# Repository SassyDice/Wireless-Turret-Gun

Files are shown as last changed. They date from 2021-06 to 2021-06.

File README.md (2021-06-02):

# Wireless Turret Gun
 Turret prototype that can be controlled both via computer and android with BT module. If you want to use the ready '.exe' file of LFK, you can download it from LFK's page. All the necessary explanations are available in the files.
# *
# *
# Kablosuz Taret Silahı
 BT modulü ile hem bilgisayar hemde android üzerinden kontrol edilebilen taret prototipi. LFK'nin hazır '.exe' dosyasını kullanmak istiyorsanız LFK'nın sayfasından indirebilirsiniz. Gerekli tüm açıklamalar dosyalarda mevcuttur.

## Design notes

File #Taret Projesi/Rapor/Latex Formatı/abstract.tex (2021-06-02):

The goal of the project; to create a turret that can be remotely controlled in line with the objectives such as ensuring life safety in military areas, gaining superiority against terrorist threats, benefiting domestic production and keeping up with the developing technology. Necessary circuits will be installed on the turret, the 3D mold of which is printed, and the movement will be carried out to lock the turret to the target through the user via computer or mobile, and this information will be sent to the turret via the wireless communication module HC-05 and its shot will be provided. In the project, servo motors are moved by the user's computer mouse or telephone touch screen and this movement is controlled by Arduino NANO microcontroller. Here the Arduino platform is used to control everything.
\vspace{3mm}

 \begin{tabular}{ll}
 	{\textbf{Keywords}:} & {Turret, Arduino, Remotely Control, Bluetooth, Military Projects.}  \\   	
 \end{tabular}

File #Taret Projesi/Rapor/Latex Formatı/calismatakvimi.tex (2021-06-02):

Çalışma Takvimi
\label{CH:Bolumcalismatakvimi}

\begin{figure}[H]
	\centering
	
   	\label{fig:CalismaTakvimiDM}
\end{figure}

\clearpage

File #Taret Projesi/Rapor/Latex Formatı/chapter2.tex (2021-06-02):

\chapter{B: ARDUİNO}
\label{IkinciBolum}

	Arduino kullanımı ilk başta pek az kişi tarafından bilinmekteydi. kökenleri ise Wiring ve Processing projelerine dayanmaktadır. Henüz programlama deneyimi olmayan kişilere programlamayı öğretebilmek amacıyla processing programlama dili ve geliştirme ortamı oluşturulmuştur. 
    Teknik bilgisi az olan insanlara bilgi besleme adına da kolaylık sağlayan arduino, çevresiyle etkileşim içinde olan interaktif nesneler oluşturmak isteyen tasarımcılar için de büyük kolaylık sağlamaktadır.
    Arduino bir Giriş/Çıkış kartı ve Processing dilinin uygulamasını da dahilinde bulunduran bir fiziksel programlama platformudur. Arduino bilgisayar üzerinde çalışan yazılımlarda kullanıldığı gibi tek başına çalışan interaktif nesneler oluşturmak için de kullanılabilir.
    
	Arduino’ nun neden bu kadar çok tercih edildiğini maddeler halinde gösterirsek:  
    
\begin{itemize}
\item Windows, Linux, Mac gibi bütün platformlarda çalışabilen geliştirme ortamı ve sürücülerinin kurulumu çok kolay olmaktadır.  
\end{itemize}

\begin{itemize}
\item Zengin bir kütüphane barındırdığından Birçok karmaşık işleme kolaylık sağlayabilmektedir.
\end{itemize}
	
\begin{itemize}
\item İçerisinde aktarılan kodlar/programlar oldukça hızlı çalışmaktadır. 
\end{itemize}

\begin{itemize}
\item Başka donanımlarla da çalışabilmesi adına ek donanımlar içermektedir. Bu karta bağlanamayan sensör çeşidi yok desek yeridir.
\end{itemize}
    
\begin{itemize}
\item Benzer diğer devre kartlarına kıyasla fiyatı oldukça uygundur.
\end{itemize}
   
\begin{itemize}
\item Açık kaynak kodlu olması kullanmak isteyen herkesin özgürlüğine olanak sağlamaktadır. Misal bir eğitim kurumu Arduino için lisans parası ödemeden rahatça kullanabilir. KAYNAK [5],[6]
\end{itemize}

\clearpage

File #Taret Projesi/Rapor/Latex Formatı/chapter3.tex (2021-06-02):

B.2: Arduino Uno 
\label{UcuncuBolum}

	Geliştirilen birçok projede kullanılan en popüler devre kartıdır. Üzerinde birkaç donanım barındırmaktadır. Bunlar: Atmega328 mikrodenetleyici, 16 MHz kristal, güç regülatörü, USB bağlantı portu, gibi bileşenler bulunuyor. Üzerindeki USB dönüştürücü sayesinde hem gerekli kodlar aktarılabilmekte hem de bilgisayar ile iletişim kurulabilmektedir. Kart, üzerindeki fiş jakı sayesinde adaptör tarafından veya üzerindeki USB portu sayesinde kurulan USB bağlantısı tarafından beslenebilmektedir. Arduino Uno kartının ön ve arka görünümü sırasıyla, Şekil 2 ve Şekil 3'de gösterilmiştir.

\begin{figure}[H]
	\centering
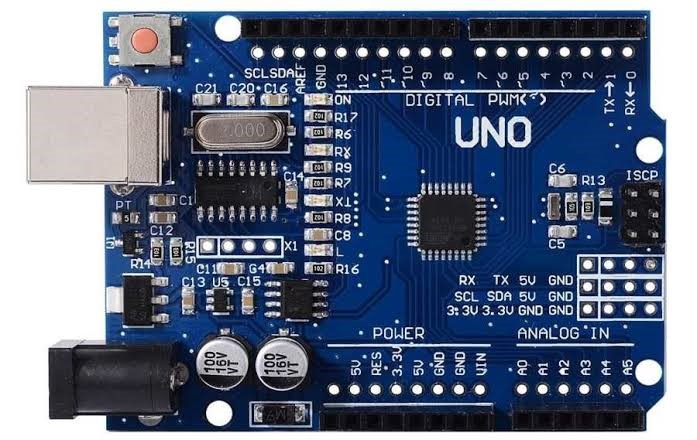
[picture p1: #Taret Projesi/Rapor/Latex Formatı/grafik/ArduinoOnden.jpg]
	
    \caption{Arduino Uno (Klon) kartının ön görünümü}
	\label{fig:ArduinoOndenDM}
\end{figure}
\begin{figure}[H]
	\centering
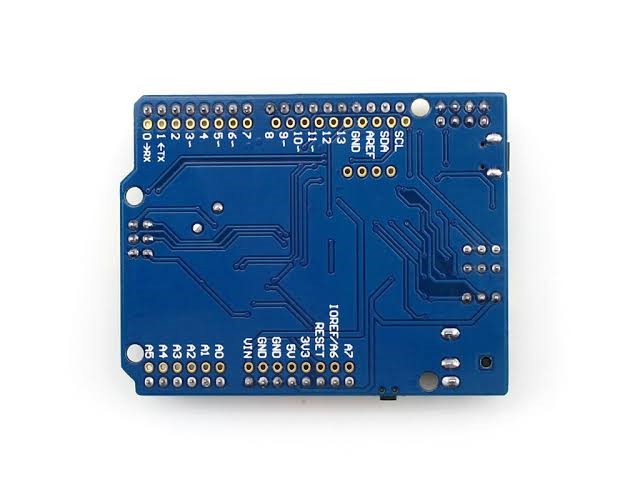
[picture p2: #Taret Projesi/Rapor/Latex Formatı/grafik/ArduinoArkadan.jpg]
	
    \caption{Arduino Uno (Klon) kartının arka görünümü}
	\label{fig:ArduinoArkadanDM}
\end{figure}

\clearpage

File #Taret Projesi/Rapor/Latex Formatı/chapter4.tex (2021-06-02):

B.3: Servo Motor
\label{DorduncuBolum}

	Servo motorlar çoğu projenin hareketini sağlamakta ve olmazsa olmazlardandır. CNC'lerde, model uçaklarda, RC arabalarda, 3D Printerlarda ve küçük güçteki birçok robot uygulamalarında kullanılmaktadır. Servo motor içerisinde geri besleme potansiyometresi, DC elektrik motoru, DC motor konum kumanda elektroniği ve planetar dişli sistemi bulunmaktadır. Bu motorlar projemde tasarlanan taretin gövde, baş ve tetikleme hareketlerini gerçekleştirmek amacıyla kullanılacaktır. Servo motorun blok diyagramı, projede kullanılan modeli ve devre şeması sırasıyla, Şekil 4, Şekil 5 ve Şekil 6’da gösterilmiştir.

\begin{figure}[H]
	\centering
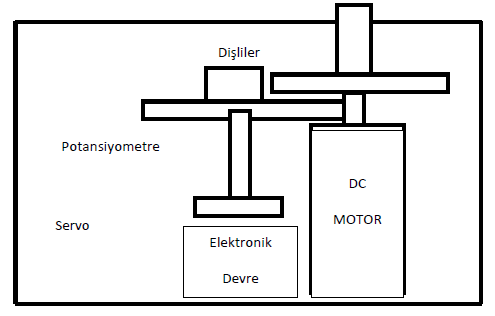
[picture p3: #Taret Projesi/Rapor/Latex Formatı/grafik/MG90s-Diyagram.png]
	
    \caption{Servo motorların genel iç blok diyagramı}
	\label{fig:MG90s-DiyagramDM}
\end{figure}
\begin{figure}[H]
	\centering
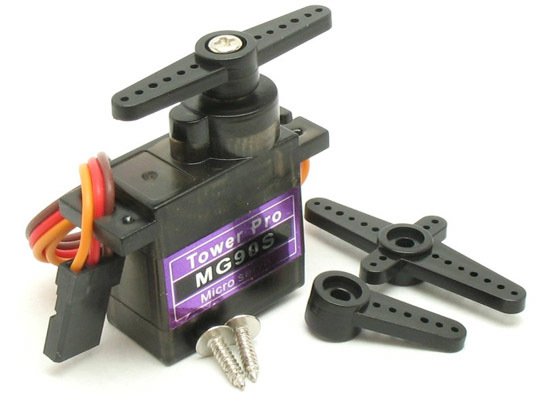
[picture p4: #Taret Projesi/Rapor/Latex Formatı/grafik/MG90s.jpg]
	
    \caption{Projede Kullanılan MG90s Servo}
	\label{fig:MG90sDM}
\end{figure}
\begin{figure}[H]
	\centering
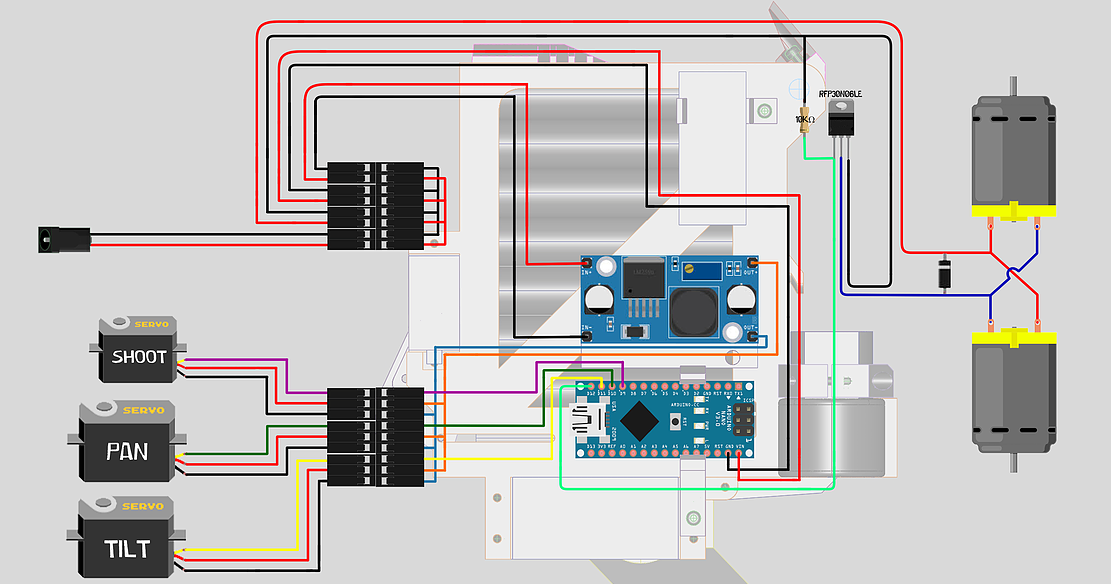
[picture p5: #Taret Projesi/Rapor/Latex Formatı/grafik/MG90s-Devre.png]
	
    \caption{Servo Motorların Projedeki Devre Şeması}
	\label{fig:MG90s-DevreDM}
\end{figure}

\clearpage

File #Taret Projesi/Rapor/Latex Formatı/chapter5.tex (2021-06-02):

\textbf{B.4: HC-05 Bluetooth Modül}
\label{YedinciBolum}

	HC-05 Bluetooth modülü,  kablosuz seri haberleşme projeleri için yapılmıştır. Bu modül bluetooth 2.0’ı destekleyen, 2.4GHz frekansında haberleşme yapılmasını sağlar. Haberleşme esnasında açık alanda yaklaşık 10 metre haberleşme mesafesine sahiptir. Modülün haberleşme bağlantısı serial yani UART olduğundan kolay ve hızlı bir kullanımı vardır. Üzerinde bulunan RX ve TX pinleri sayesinde iletişim sağlanır. Bu pinler kullanılacak olan devre kartınının sırasıyla TX ve RX pinlerine bağlanır. Ayrıca bu pinler yardımıyla AT komutlarını kullanarak modülün isim, şifre,baud rate değeri, gibi çeşitli özellikleri değiştirebilir. KAYNAK [3]
    
	Projede ise bu modül kablosuz haberleşme için kullanılmaktadır. Bilgisayar veya mobil üzerinden alınan analog veriler bu modül sayesinde tarete aktarılmaktadır. Bu sayede kullanıcı tarafından yapılan hareketleri anlık olarak taret üzerinde de gözlemleyebiliriz. Bluetooth modül Şekil 7de gösterilmiştir.

\begin{figure}[H]
	\centering
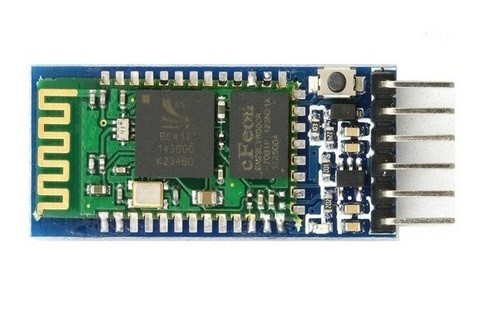
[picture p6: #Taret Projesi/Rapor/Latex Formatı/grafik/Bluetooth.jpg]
	
    \caption{Projede Kullanılan HC-05 Bluetooth Modülü}
	\label{fig:BluetoothDM}
\end{figure}

\textbf{Dikkat:} HC-05 Bluetooth modülü devre kartındaki 3.3V pinine bağlantı yapılarak veya uçları arasında dirençler bağlayarak çalıştırılması gerekmektedir. HC-06 Bluetooth modülü ise 5V pinine bağlantı yapılarak veya yine direnç bağlanarak çalıştırılmalıdır.

\textbf{Bilgi:} Kodları hatasız bir şekilde Arduino’ya aktarabilmek için Arduino üzerindeki RX ve TX pinlerine bağlı kabloları aktarma işleminden önce sökmek gerekiyor. Bu işlem yapılmazsa kod aktarımı sırasında portların meşgul olduğuna dair hata alabiliriz. 

\clearpage

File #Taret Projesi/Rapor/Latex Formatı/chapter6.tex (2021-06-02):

\textbf{B.5: 3D Taret Modeli}
\label{SekizinciBolum}

Taretin baskısı 3D yazıcılar vasıtasıyla PLA+  Filament kullanılarak yapıldı. Kendi oluşturmuş olduğum 3D modelleri ile Github üzerindeki üyerlerin modellerini mix ederek aşağıdaki modelleri elde etmiş oldum. 3D modeli oluşturmak için Blender programını kullandım. Taretin 3D modelleri Şekil 9’da gösterilmiştir. KAYNAK [1]

\begin{figure}[H]
	\centering
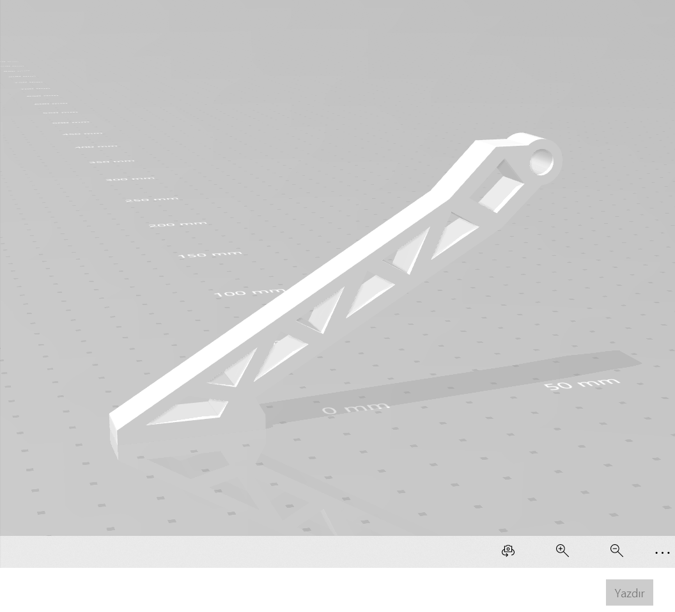
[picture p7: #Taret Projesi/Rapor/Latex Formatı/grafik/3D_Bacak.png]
	
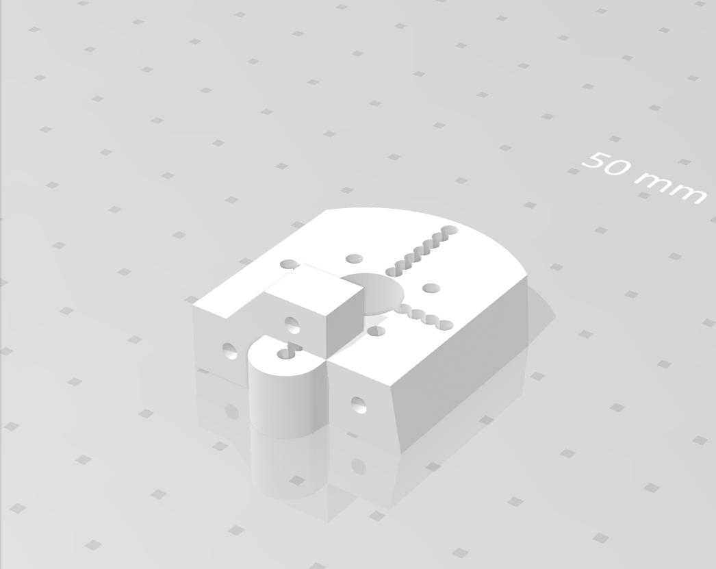
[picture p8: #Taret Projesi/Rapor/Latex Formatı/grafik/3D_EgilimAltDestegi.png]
    
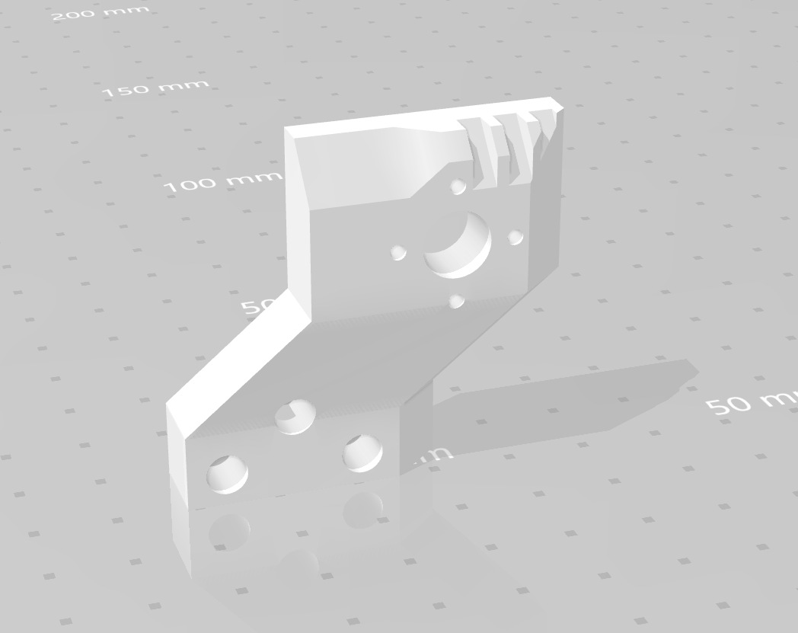
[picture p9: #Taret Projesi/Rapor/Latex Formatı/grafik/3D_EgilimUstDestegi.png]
    
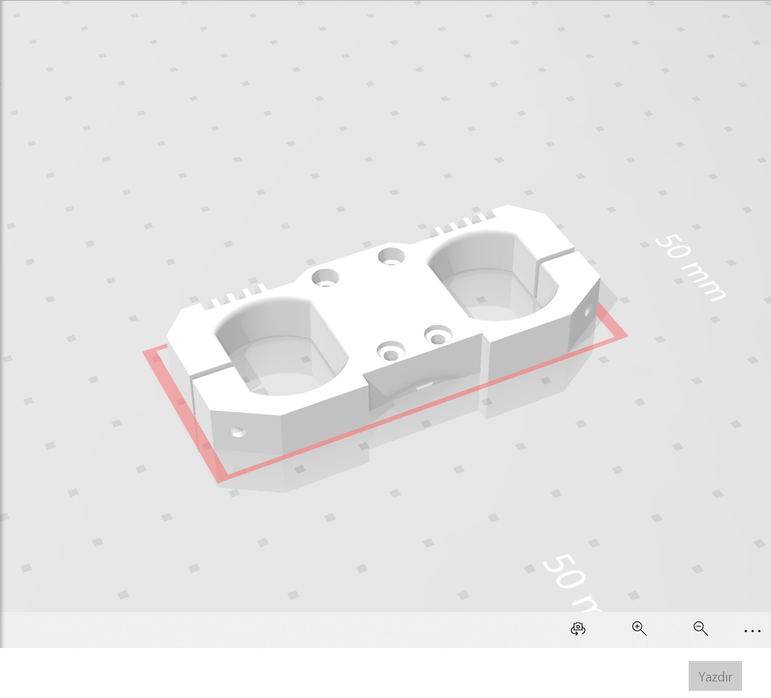
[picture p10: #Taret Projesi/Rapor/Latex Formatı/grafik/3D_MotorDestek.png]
    
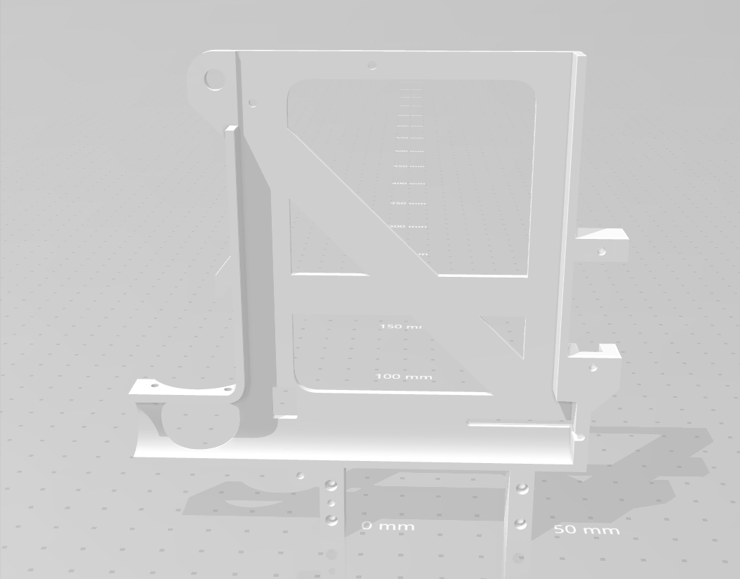
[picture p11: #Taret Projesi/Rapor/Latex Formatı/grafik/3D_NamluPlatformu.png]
    
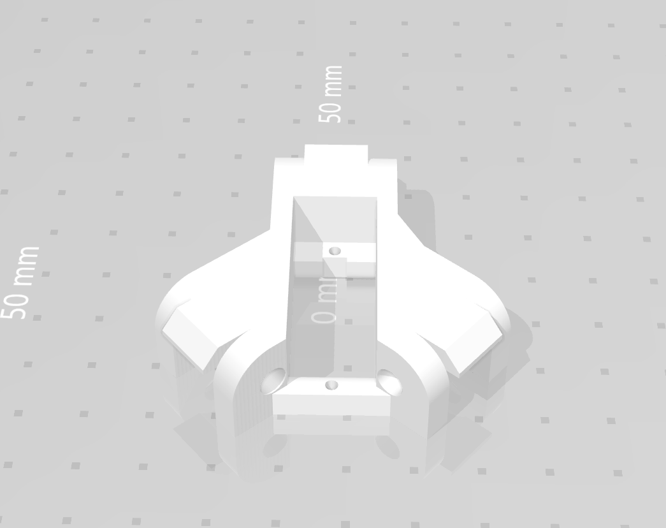
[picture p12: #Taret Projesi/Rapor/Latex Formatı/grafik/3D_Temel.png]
    
    
    \caption{Taret 3D Model Örnekleri}
    \label{fig:Taret1,2,3,4,5,6DM}
\end{figure}

\clearpage

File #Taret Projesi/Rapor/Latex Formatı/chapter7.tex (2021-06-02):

\textbf{C: Programlama Aşaması }
\label{DokuzuncuBolum}

Tüm devrelerin montajı tamamlandı ve projenin programlama aşamasına geçildi. Bu aşamada ilk önce fare hareketlerinin analog değerleri serial monitörden okunarak hassasiyet değerlendirmesi maksatıyla tam değerleri bulundu. Arduino NANO devre kartı ise okunan değerleri projede kullanılan servo motorlara dikey ve yatay açısal bilgileri gönderecek şekilde programlandı. Tüm kodlamalar Arduino IDE programı vasıtasıyla Bilgisayardan USB kablo ile Arduino NANO Mikrodenetleyicisine aktarıldı.

\begin{figure}[H]
	\centering
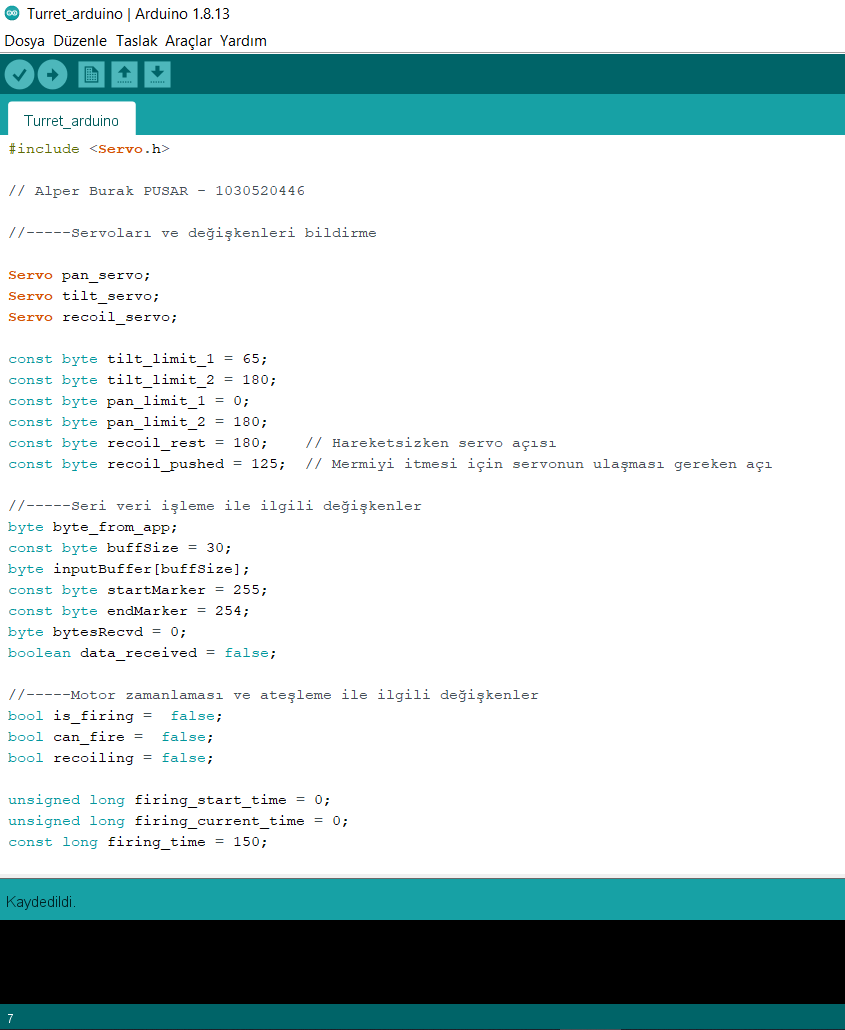
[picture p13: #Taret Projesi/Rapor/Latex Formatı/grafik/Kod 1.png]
	
	\label{fig:KodDM}
\end{figure}
\begin{figure}[H]
	\centering
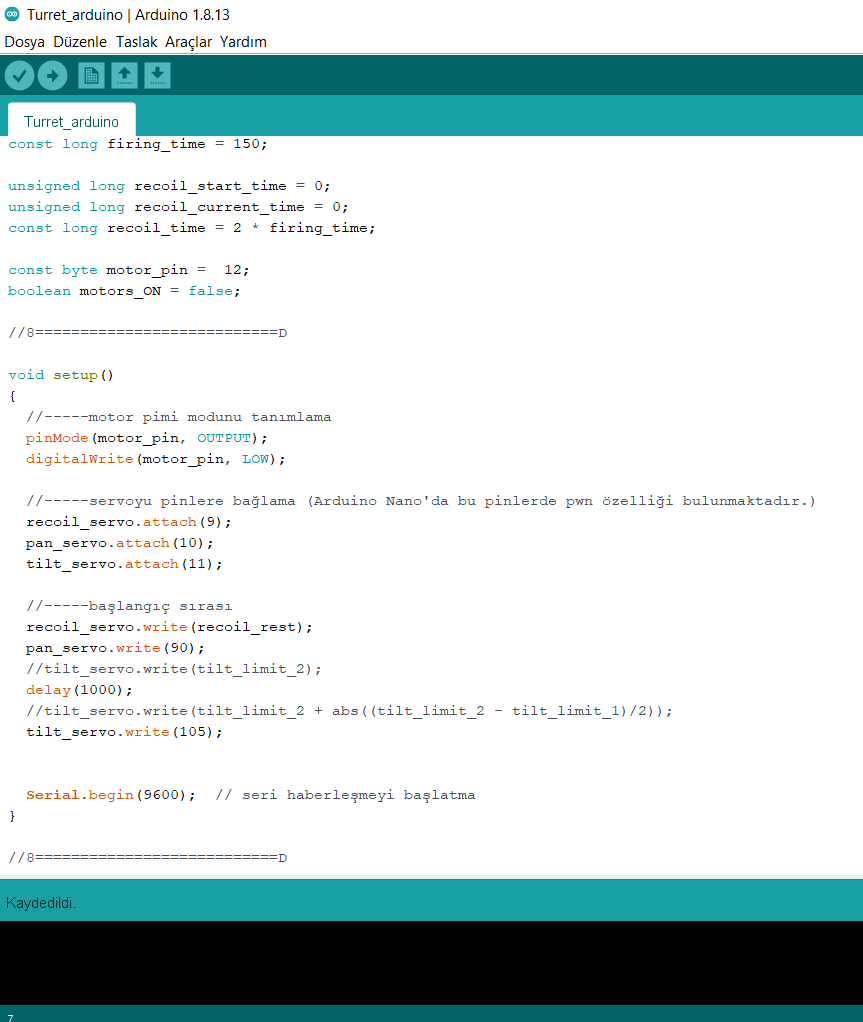
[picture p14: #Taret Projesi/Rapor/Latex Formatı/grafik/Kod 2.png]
	
	\label{fig:KodDM}
\end{figure}
\begin{figure}[H]
	\centering
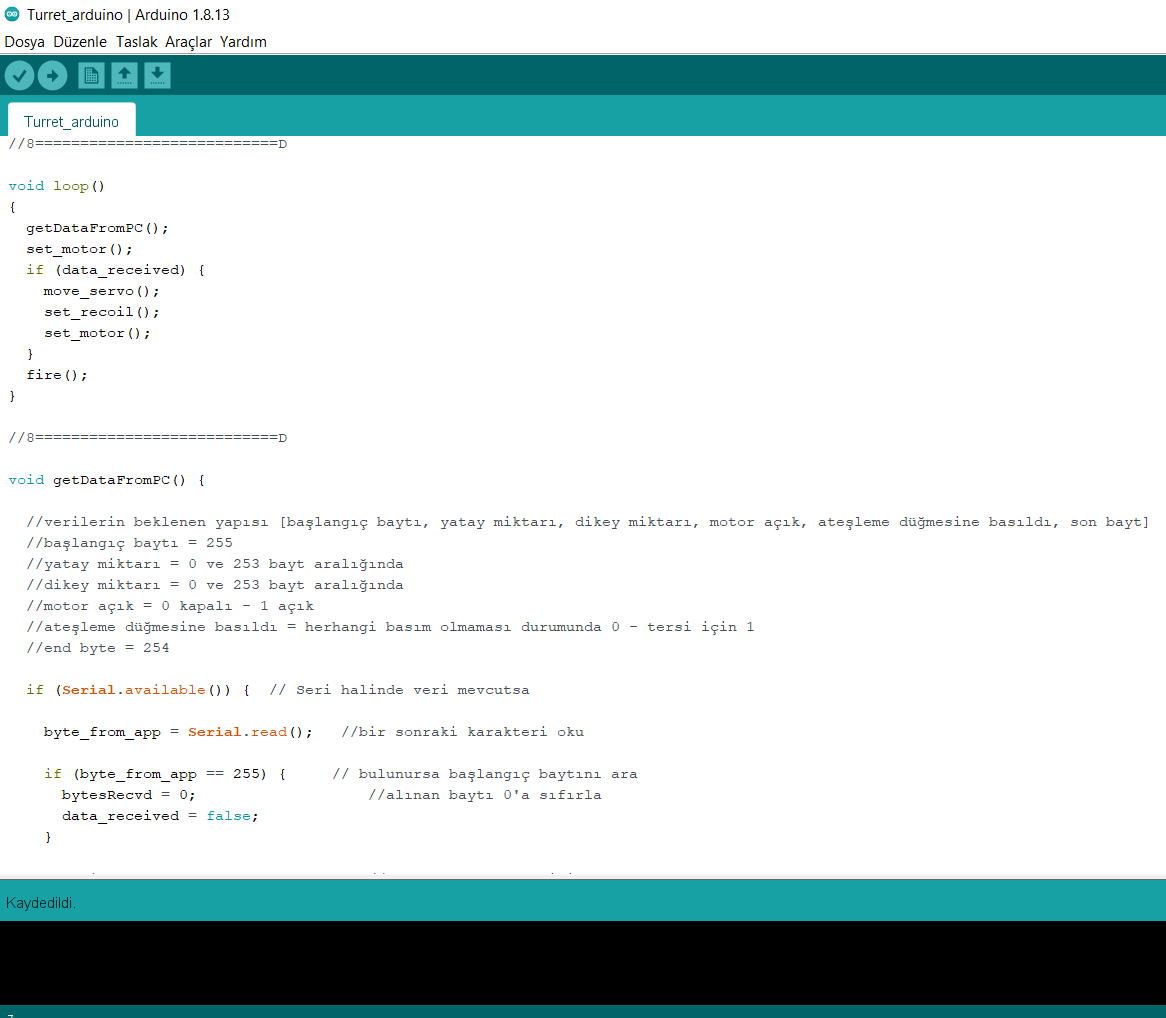
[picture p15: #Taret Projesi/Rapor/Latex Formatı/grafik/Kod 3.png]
	
	\label{fig:KodDM}
\end{figure}
\begin{figure}[H]
	\centering
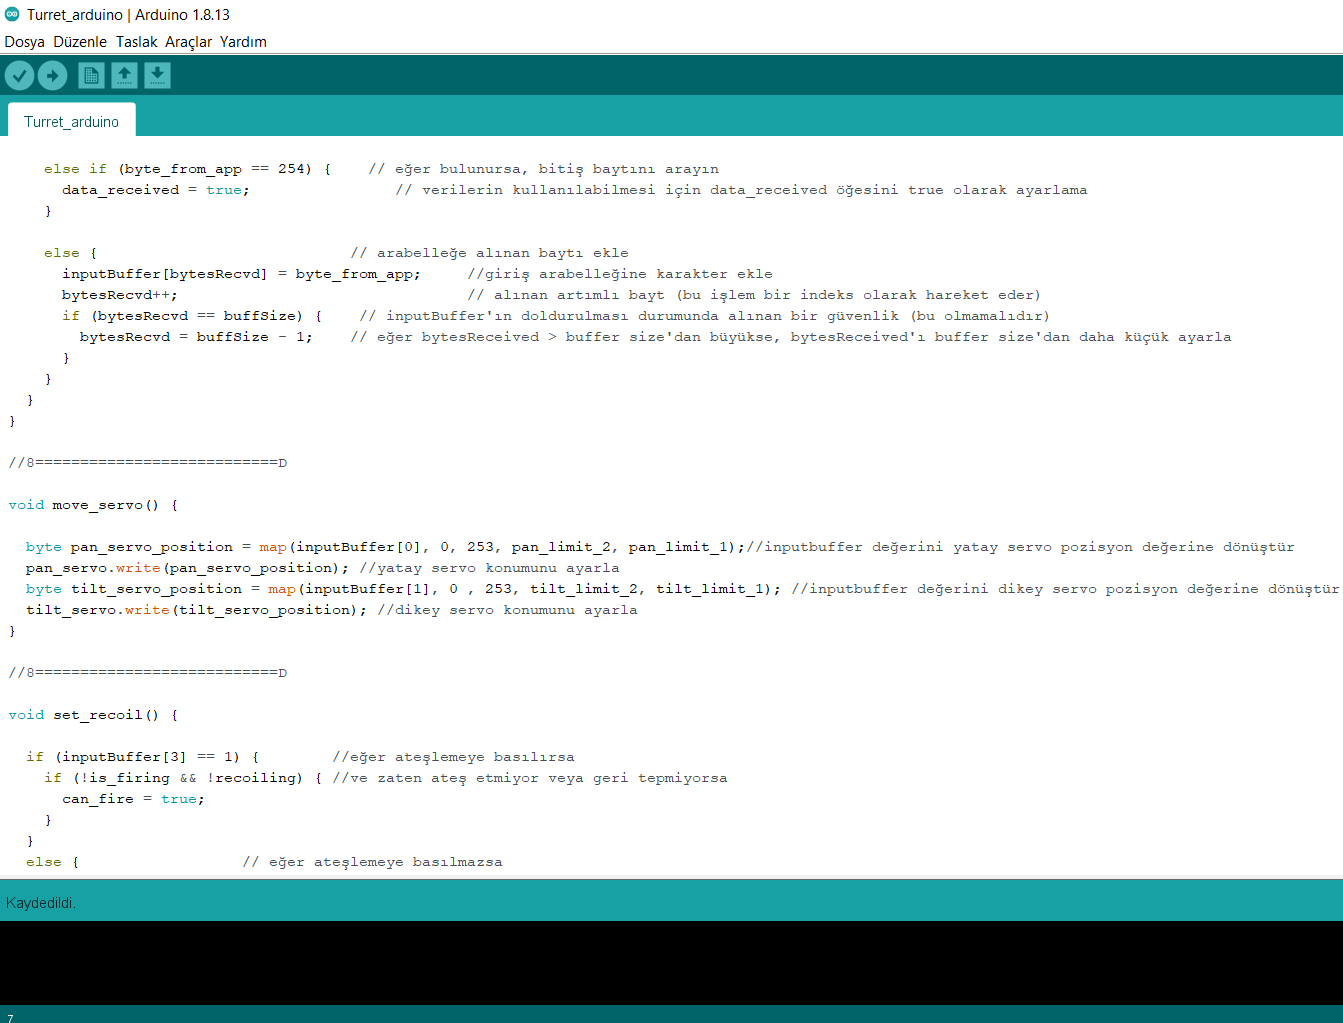
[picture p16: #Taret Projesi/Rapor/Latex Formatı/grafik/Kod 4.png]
	
	\label{fig:KodDM}
\end{figure}
\begin{figure}[H]
	\centering
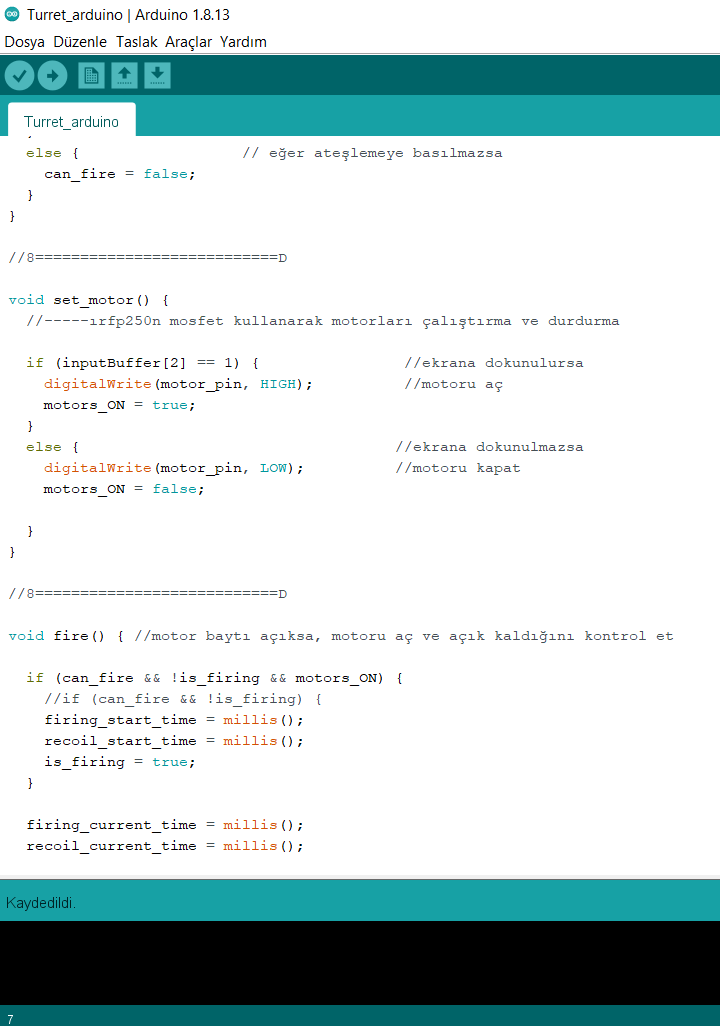
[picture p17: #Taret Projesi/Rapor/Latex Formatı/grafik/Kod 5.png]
	
	\label{fig:KodDM}
\end{figure}
\begin{figure}[H]
	\centering
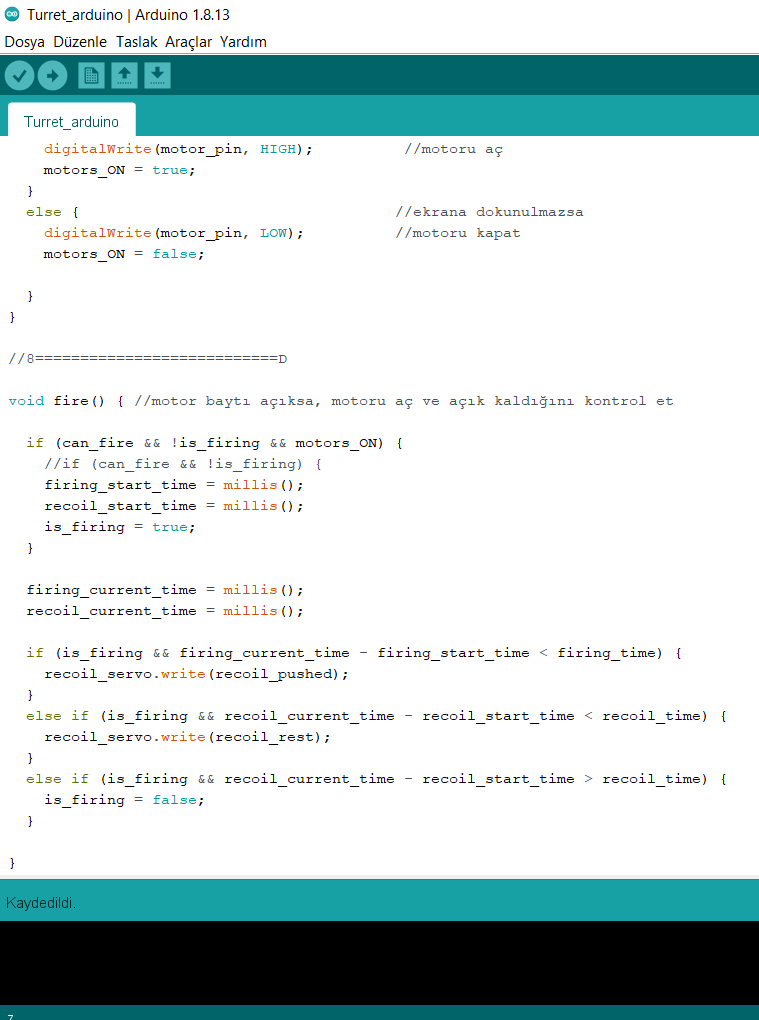
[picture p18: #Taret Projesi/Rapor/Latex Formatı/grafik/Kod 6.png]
	
	\label{fig:KodDM}
\end{figure}

\clearpage

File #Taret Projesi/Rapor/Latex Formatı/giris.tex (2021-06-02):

\label{CH:BolumGiris}

Günümüz teknolojisinde endüstriyel, tıp ve askeri alanlar başta olmak üzere birçok alanda robotik sistemlere olan ilgi artmaktadır. Hobi olarak veya üniversite proje yarışmaları ile yapılan robotik sistemlerin yanı sıra askeri güç amaçlı, uluslararası rekabet ve ülke sınırları dahilindeki terör sorununu bitirmek amaçlı yapılan ve özellikle de AR-GE çalışmaları sonucu ortaya çıkarılan birçok savunma sanayi ürünü sunulmuştur. Tasarladığım uzaktan kontrollü taret projesinin, bir insanın yapamayacağı derecede hassasiyet elde ederek hedefe net kitlenebilme ve daha da önemlisi can kaybının azalacağına yönelik büyük hizmet sunacağı düşünülmektedir. Bu proje 3D yazıcı yardımıyla tasarlanmış taretin, kullanıcının vereceği komutları doğru uygulayabilmesi esasına dayanmaktadır. Tasarlanan taretin devrelerine bağlı durumda bulunan HC-05 Bluetooth modeli, işlevini uzaktaki bir kullanıcının vereceği komutları veri kaybı olmadan tarete ulaştırabilmesi amacıyla devreye eklenmiştir. Kullanıcı ile taret arasındaki haberleşme kablosuz olarak sağlanmıştır. Proje, bilgisayar veya mobil ile uyumlu nitelikte olacaktır.  Eğer ki bilgisayar üzerinden haberleşme sağlanıyorsa, fare üzerindeki hareketilerin veri kodları arduino uyumu için  kendi kütüphanesine bağlı kodlar vasıtasyıla compile edilir ve servo motorlara iletilir. Hem gövde hem de baş kısmında bulunan servolar sayesinde yatay ve dikey hareket kabiliyeti tarete akatarılmış olur. Plastik mermilerin atışının gerçekleşmesi ise namlu ucuna yerleştirilen 2 adet DC motorun sürekli dönüşü sayesinde ikisinin arasına temas eden mermiyi hızlı bir ivmeyle fırlatması şeklinde gerçekleşir. Tüm bu işlemlerin programlanması Arduino NANO mikrodenetleyicisi üzerinden kurulan devre sayesinde kontrol edilmiştir.

\clearpage

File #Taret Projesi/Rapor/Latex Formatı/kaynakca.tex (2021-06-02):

\textbf{KAYNAKLAR}
\label{CH:BolumKaynakca}

[1]. Github Users, Multi persons, Arduino Turret, Available: https://github.com/

[2]. The Extendedsystem website. Available: http://www.extendedsystems.com/

[3]. Haartsen, J. C., The Bluetooth Radio System, IEEE Personal Communications 

[4]. Çamoğlu, D., Kontrollü Robotik, Dikeyeksen Yayıncılık, Şubat 2011. 

[5]. Taşdemir, C., Arduino, Dikeyeksen Yayın Dağıtım, Yazılım ve Eğitim Hizmetleri San. ve Tic. Ltd. Şti., İstanbul, 2012. 

[6]. D. İbrahim, PIC Mikrokontrolör Robot Projeleri, Bileşim Yayıncılık Fuarcılık ve Tanıtım Hizmetleri A.Ş., İstanbul, Türkiye, 2005.

\clearpage

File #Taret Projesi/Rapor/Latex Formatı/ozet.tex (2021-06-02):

\label{CH:BolumOzet}

Projenin amacı; askeri alanlarda can güvenliğini sağlamak, terör tehtitlerine karşın üstünlük sağlamak, yerli malı üretimine fayda sağlamak ve gelişen teknolojiye ayak uydurmak gibi hedefler doğrultusunda uzaktan kontrol edilebilen bir taret ortaya çıkarmaktır. 3D kalıbı basılan taretin üzerine gerekli devreler kurulup, bilgisayar veya mobil üzerinden kullanıcı aracılığıyla taretin hedefe kitlenmesi için hareketi gerçekleştirilecek. Bu bilgiler HC-05 bluetooth modülü aracılığıyla tarete anlık veri akışları gönderip atışı sağlanacaktır. Projede, kullanıcının bilgisayar faresi veya telefon dokunmatik ekranı vasıtasıyla servo motorlar hareket ettirilmektedir. Yapılan tüm bu işlemler Arduino NANO ile kontrol edilmektedir.
               
\clearpage

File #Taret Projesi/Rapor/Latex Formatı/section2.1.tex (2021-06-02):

\clearpage
\section{B.1: Arduino Çeşitleri: }
\label{CH:AltBolum2.1}

1. Arduino Uno 	

2. Arduino Nano	

3. Arduino Mega  

4. Arduino Mini ve Mini Pro 

5. Arduino Bluetooth 

6. Arduino Lilypad 20 	

7. Arduino Leonardo

8. Arduino Adk 		

9. Arduino Ethernet

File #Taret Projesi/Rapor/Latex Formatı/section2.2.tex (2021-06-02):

\clearpage
\section{B.1.1: KULLANILAN MALZEMELER}
\label{CH:AltBolum2.2}

Arduino Nano 		x 1 --------------------------------------- 9v Pil				x 1

M2x10 Vida			 30 civarı	---------------------------------- M5x20 Vida x3

MG90s - Servo Motor	  x 3 ----------------------------- Makaron Kablo

HC-05 Bluetooth Modül 	x 1 -------------------------- LM2596 Voltaj Regülatörü x1

3D Printer Taret Kalıbı -------------------------------- Dirençler (10k, 330, 680) x3

FR207 Doğrultucu Diyot			x 1 -------------------------- Super Glue + Spray

Jumper Kablo --------------------------------------------- 2.1x5.5mm Jak Fişi x1

RFP30N06LE mosfet   x1 -------------------------------- Type 130 DC Motor x2

1.5mm Metal Çubuk x1 --------------------------------- Dupont Konnektörler

\begin{figure}[H]
	\centering
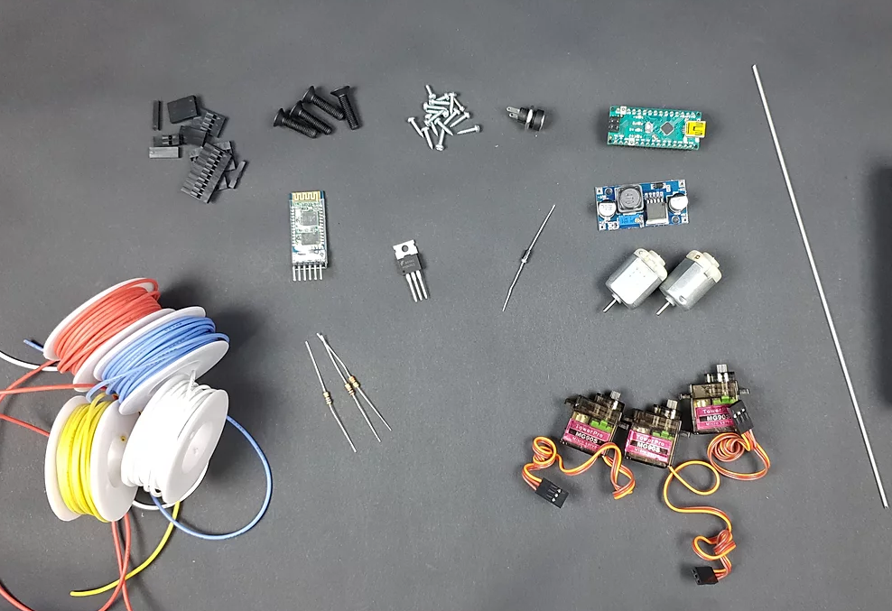
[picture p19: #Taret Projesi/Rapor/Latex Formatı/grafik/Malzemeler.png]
	
    \caption{Not: Projede Kullacağım Malzemeler (Bazı parçaları eksik ve 3D kalıp hariç görüntüsüdür.)}
	\label{fig:MalzemelerDM}
\end{figure}

\clearpage

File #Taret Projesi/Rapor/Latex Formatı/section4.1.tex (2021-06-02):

\textbf{B.3.1: TEKNİK ÖZELLİKLER:}
\label{CH:AltBolum4.1}

MG90s Servo Motor Özellikleri:

•	Çalışma tork: 2 kg/cm

•	Hızı: 0.11 sn/60° (4.8 V)

•	Çalışma aralğığı: 4.8 - 6.0 V

•	Çalışma sıcaklığı: 0°-55°

•	Ölü bant ayarı: 5 mikrosaniye

•	Dönme açısı: 180 derece

•	Çalışma gerilimi: 4.8 V - 6.0 VDC

•	Yapısal Malzeme: bakır metal diş, çekirdeksiz motor, çift bilyalı rulman

•	Boyutu: 23 x 12x 29 mm

\clearpage

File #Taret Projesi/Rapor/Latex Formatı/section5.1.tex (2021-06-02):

\textbf{B.4.1: TEKNİK ÖZELLİKLER:}
\label{CH:AltBolum7.1}

•	Çalışma Gerilimi: 3.3 V - 5 V,

•	Akım: 50 mA,

•	Bluetooth Protokolü: Bluetooth 2.0+EDR,

•	Haberleşme frekansı 2.4GHz,

•	Hassasiyet: ≤-80 dBm,

•	Çıkış Gücü: ≤+4 dBm,

•	Asenkron Hız: 2.1 MBps/160 KBps,

•	Senkron Hız: 1 MBps/1 MBps,

•	Güvenlik: Kimlik Doğrulama ve Şifreleme,

•	Boyutları: 43 x 16 x 7mm,

HC-05 Modülünün devre şeması Şekil 8’de gösterilmiştir.

\begin{figure}[H]
	\centering
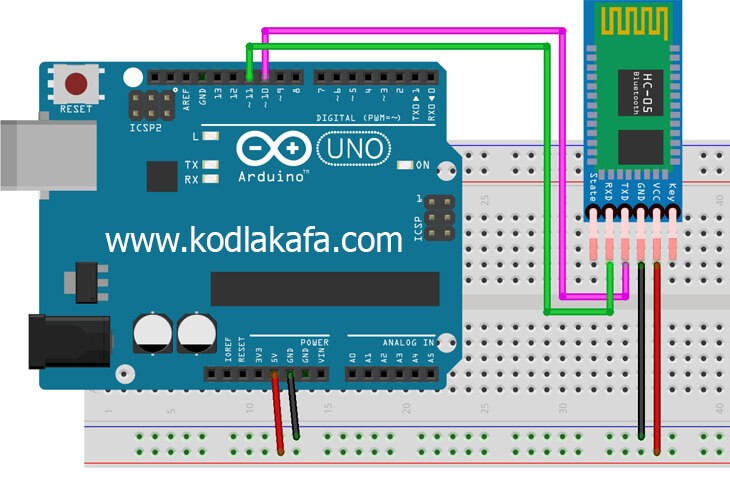
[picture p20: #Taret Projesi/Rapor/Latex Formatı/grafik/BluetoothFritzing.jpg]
	
    \caption{HC-05 Modülünün Bağlanma Şekli (Fritzing)}
	\label{fig:BluetoothFritzingDM}
\end{figure}

\clearpage

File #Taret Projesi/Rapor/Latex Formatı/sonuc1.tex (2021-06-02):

\textbf{D: SONUÇLAR }
\label{BolumSonuc}

	Yazılım ve Elektronik alanlarında yapılan yeni projeler ve devam eden çalışmaların en önemlileri insan sağlığını koruyacak türde veya global teknolojiye ayak uydurarak askeri ya da endüstriyel alanlarda gelişime açık olanlarıdır. Bu fikirle başladığım projeyi tamamlamak için amaçladığım gibi tareti kontol eden kişinin verdiği komutları veri kaybı olmadan tarete ulaşmasını sağlayabilmek vasıtasıyla tasarlanan taretin hedefe isabetli atışlarını gerçekleştirdim. Bu işlemin kullanıcı ve taret arasında kablosuz haberleşme ile sağlandığını vurgulamak gerekir.
    
Bu projeyi gerçekleştime aşamalarında birçok sıkıntıyla karşılaştım. İlk karşılaştığım sıkıntı satın almış olduğum arduino nano kartında arıza olmasıydı. Bu kartın hatalı olduğunu anlatıktan sonra yenisi temin ettim. ancak bu bozuk kartla işlem yapmaya kalkarken sanırsam hc-05 bluetooth modülümün de hasar aldığını farkettim ve onu da değiştirmek zorunda kaldım. Projede kullanılmasını uygun gördüğim FR207 hızlı diyot ve rfp30n06le mosfeti birçok yerde aradım ancak bulamadım. diyotun özellikleri 2A 100V değerlerini gösterirken mosfet ise 30A 60V değerlerini göstermekte. Ancak değindiğim gibi bu modülleri temin edemedeğimden bunların yerine BY298 hızlı diyot (2A 400V) ve ırfp250n mosfet (30A, 200V) modüllerini kullanmaya karar verdim. Bu modüller DC motorlara bağlantı kurduğundan, muhtemelen bu karar değişimden dolayı proje testi esnasında asıl büyük sıkıntıyı burada yaşadım. DC motorların güç kaçağı veya geri besleme gibi sıkıntılardan olsa gerek devreyi stabil tutamadım. bu kısım beni gerçekten çok uğraştırdı. İlk başlarda sıkıntının ne olduğunu da tam anlayamadım. En sonunda Voltaj dengesini sağlayarak devreyi stabil tutabildim.

Projenin sunumunu ayrı şekilde temin edeceğimden bu final tezine ekleme yapabileceğim kodlama, sonuç ve yorumlamalardan başka birşey kalmıyor. Zaten projenin son halini yazımdan çok videodaki anlatıma döktüm. Eminim yeterli gelecektir.

\clearpage

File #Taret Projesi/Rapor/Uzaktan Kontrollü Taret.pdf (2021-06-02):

T.C.

## ERCİYES ÜNİVERSİTESİ MÜHENDİSLİK FAKÜLTESİ

## UZAKTAN KONTROLLÜ TARET

## Hazırlayan

## Alper Burak PUSAR

1030520446

## Danışman Doç. Dr. Celal ÖZTÜRK

## Bilgisayar Mühendisliği

## Bitirme Ödevi

## Temmuz 2020 KAYSERİ

i

“Uzaktan Kontrollü Taret” adlı bu çalışma, jürimiz tarafından Erciyes

Üniversitesi Bilgisayar Mühendisliği Bölümünde Bitirme Ödevi olarak kabul

edilmiştir.

13/07/2020

JÜRİ :

Danışman : Doç. Dr. Celal ÖZTÜRK

Üye | :
Üye | :

ONAY :

Yukarıdaki imzaların, adı geçen öğretim elemanlarına ait olduğunu onaylarım.

.... / .... /20...
Prof.Dr. VEYSEL ASLANTAŞ
Bilgisayar Müh. Bölüm
Başkanı

ii

ÖNSÖZ / TEŞEKKÜR

Bilindiği üzere günümüz çağında işlerin kolaylığını sağlamak amacıyla elektrik ve

yazılım dalında, farklı alanlarda farklı çalışmalar yapılmaktadır. Bu iki dalın

birleşimi bizlere daha çok robotik alanda projeler yapmamıza olanak sağlıyor. Bu

projelerden en önemlileri ise endüstriyel ve askeri alanlarındaki zorlukları sürekli

gelişen teknolojiye uyarlayarak işleri basitleştirmeyi ve ülke savunmasını geliştirmeyi

amaçlayan çalışmalardır. ‘’Uzaktan Kontrollü Taret” isimli proje bu fikirler

doğrultusunda, insan kontrolüyle verilen komutu veri yoluyla (kablosuz) tarete

aktararak, hedefine isabetli atış yapabilmek ve ülke savunmasını geliştirmek amacıyla

yapılmaya karar verilmiştir.

iii

UZAKTAN KONTROLLÜ TARET

Alper Burak PUSAR
Erciyes Üniversitesi, Bilgisayar Mühendisliği Danışman : Doç. Dr. Celal ÖZTÜRK

ÖZET

Projenin amacı; askeri alanlarda can güvenliğini sağlamak, terör tehtitlerine karşın

üstünlük sağlamak, yerli malı üretimine fayda sağlamak ve gelişen teknolojiye ayak

uydurmak gibi hedefler doğrultusunda uzaktan kontrol edilebilen bir taret ortaya

çıkarmaktır. 3D kalıbı basılan taretin üzerine gerekli devreler kurulup, bilgisayar

veya mobil üzerinden kullanıcı aracılığıyla taretin hedefe kitlenmesi için hareketi

gerçekleştirilecek. Bu bilgiler HC-05 bluetooth modülü aracılığıyla tarete anlık

veri akışları gönderip atışı sağlanacaktır. Projede, kullanıcının bilgisayar faresi

veya telefon dokunmatik ekranı vasıtasıyla servo motorlar hareket ettirilmektedir.

Yapılan tüm bu işlemler Arduino NANO ile kontrol edilmektedir.

iv

Remote Controlled Turret

Alper Burak PUSAR
Erciyes University, Computer Engineering Supervisor: (Associate Professor) Celal ÖZTÜRK

ABSTRACT

The goal of the project; to create a turret that can be remotely controlled in line

with the objectives such as ensuring life safety in military areas, gaining superiority

against terrorist threats, benefiting domestic production and keeping up with the

developing technology. Necessary circuits will be installed on the turret, the 3D

mold of which is printed, and the movement will be carried out to lock the turret

to the target through the user via computer or mobile, and this information will

be sent to the turret via the wireless communication module HC-05 and its shot

will be provided. In the project, servo motors are moved by the user’s computer

mouse or telephone touch screen and this movement is controlled by Arduino NANO

microcontroller. Here the Arduino platform is used to control everything.

Keywords: Turret, Arduino, Remotely Control, Bluetooth, Military Projects.

İÇİNDEKİLER

UZAKTAN KONTROLLÜ TARET

### 1. BÖLÜM

A : ROBOT NEDİR?

### 2. BÖLÜM

B: ARDUİNO

vi

ŞEKİLLER LİSTESİ

Şekil 2.1. Not: Projede Kullacağım Malzemeler (Bazı parçaları eksik ve 3D

vii

KISALTMALAR

V - Gerilim

Kb - Kilo bit

R - Direnç

Kb/sn - Kilo bit/saniye

I - Akım

Mb - Mega bit

d - Uzaklık

m - Metre

A - Analog Giriş

L - Uzunluk

I - Giriş

S - Dik kesit alanı

O - Çıkış

GİRİŞ

Günümüz teknolojisinde endüstriyel, tıp ve askeri alanlar başta olmak üzere birçok

alanda robotik sistemlere olan ilgi artmaktadır. Hobi olarak veya üniversite proje

yarışmaları ile yapılan robotik sistemlerin yanı sıra askeri güç amaçlı, uluslararası

rekabet ve ülke sınırları dahilindeki terör sorununu bitirmek amaçlı yapılan ve

özellikle de AR-GE çalışmaları sonucu ortaya çıkarılan birçok savunma sanayi

ürünü sunulmuştur. Tasarladığım uzaktan kontrollü taret projesinin, bir insanın

yapamayacağı derecede hassasiyet elde ederek hedefe net kitlenebilme ve daha da

önemlisi can kaybının azalacağına yönelik büyük hizmet sunacağı düşünülmektedir.

Bu proje 3D yazıcı yardımıyla tasarlanmış taretin, kullanıcının vereceği komutları

doğru uygulayabilmesi esasına dayanmaktadır. Tasarlanan taretin devrelerine

bağlı durumda bulunan HC-05 Bluetooth modeli, işlevini uzaktaki bir kullanıcının

vereceği komutları veri kaybı olmadan tarete ulaştırabilmesi amacıyla devreye

eklenmiştir. Kullanıcı ile taret arasındaki haberleşme kablosuz olarak sağlanmıştır.

Proje, bilgisayar veya mobil ile uyumlu nitelikte olacaktır. Eğer ki bilgisayar

üzerinden haberleşme sağlanıyorsa, fare üzerindeki hareketilerin veri kodları arduino

uyumu için kendi kütüphanesine bağlı kodlar vasıtasyıla compile edilir ve servo

motorlara iletilir. Hem gövde hem de baş kısmında bulunan servolar sayesinde

yatay ve dikey hareket kabiliyeti tarete akatarılmış olur. Plastik mermilerin atışının

gerçekleşmesi ise namlu ucuna yerleştirilen 2 adet DC motorun sürekli dönüşü

sayesinde ikisinin arasına temas eden mermiyi hızlı bir ivmeyle fırlatması şeklinde

gerçekleşir. Tüm bu işlemlerin programlanması Arduino NANO mikrodenetleyicisi

üzerinden kurulan devre sayesinde kontrol edilmiştir.

2

Çalışma Takvimi

### 1. Çalışma Takvimi

TARİH YAPILAN İŞ | 10 -15 MAYIS | 15 -25 MAYIS | 25 -31 MAYIS | 1 -10 HAZİRAN | 10 -25 HAZİRAN | 25 -30 HAZİRAN | 1 -10 TEMMUZ | 12 TEMMUZ

PROJE İÇİN GEREKLİ TÜM ARAŞTIRMALARIN YAPILMASI

TARET TASARIMININ GERÇEKLEŞMESİ

GEREKSİNİM ANALİZİ

GEREKLİ TÜM PARÇALARIN SİPARİŞLERİ

TÜM PARÇALARIN 3D KALIBA MONTAJI VE ELEKTRONİK PARÇALARIN TEST EDİLMESİ

GEREKLİ KODLARIN OLUŞTURULMAYA BAŞLAMASI

TARETE SERVO MOTORLARIN MONJATI VE TESTİ

RECEIVER İÇİN OLAN BLUETOOTH MODÜLÜNÜN TEST EDİLMESİ

PROJENİN TEST EDİLMESİ İÇİN SON KONTROLLER VE GÖZDEN GEÇİRME

PROJENİN TESTİ

### 1. BÖLÜM

A : ROBOT NEDİR?

Robotlar doğayı taklit eden insan hayatını kolaylaştıran makinelerdir. Robotlar,

otonom ya da kumanda edilen, algılayıcıları, kontrol sistemi ve bedensel yapıları

ile nesneleri tutmak, kavramak, hareket ettirmek, taşımak, üretim yapmak gibi

amaçları yerine getirebilen elektronik, mekanik veya simetrik yapılardan oluşan

yapay sistemlerdir.

4

### 1.1. A.1: Robotların Tarihsel Gelişimi

Robot kelimesi ilk olarak 1921 yılında sunulmuş olan bir tiyatro oyununda karşımıza

çıkar. Ünlü Çek bilim kurgu yazarı Karel Capek tarafından yazılmış R.U.R. oyunu

Çekoslavakya’ da sahnelenmiş bir bilim kurgu yapıtıdır. Yazar, kendi dili Çekce’

de işgücü anlamına gelen "robota" kelimesini oyunda kullanmış ve bu kelimenin

lüteratürlere geçmesine yol açmıştır. KAYNAK [4]

5

### 1.2. A.2: HABERLEŞME

Haberleşme sistemleri temel olarak 3 elemandan oluşur:

- Verici

Sistemdeki verici tarafından gönderilen bilgi alıcıya iletilmesinden önce iletilecek

hale getirilir (yani veriye dönüştürülür), kendi güç kapasitesine göre iletim

yaptığı mesafenin değişmesi süretiyle, gerekli kodlamaları yapar, hatta gerekirse

kuvvetlendirme de yapılır.

- İletim Ortamı

Sistemler arasındaki iletim ortamı verici tarafından sinyalin iletildiği ortama verilen

isimdir. Bu iletim ortamları kablolu ve kablosuz olmak üzere ikiye ayrılır. Kablolu

İletim Ortamının tanımını yaparsak; verilerin iletimi yanlızca bu kabloların bağlı

olduğu modüller arasında gerçekleşir. Bakır, fiber optik, bükümlü, koaksiyel

kablolar vs. Kablosuz İletim Ortamının tanımı ise; bu ortamlarda iletişim, veriler

en uygun alıcıyı kullanarak TV ve radyo yayınlarındaki gibi herkes tarafından

alınabilmektedir. En verimli ortamları hava, su, boşluk vs. gibi doğal ortamlardır.

- Alıcı

Vericide toplanan bilgi, bahsi geçen iletim ortamlarından geçtikten sonra alıcıya

gelir.

6

### 1.3. A.3: Kablosuz İletişim

Günümüzde kablolu haberleşmenin yanında kablosuz haberleşme de oldukça

yaygınlaşmıştır. Bu kablosuz haberleşmeler kullanıcılara herhangi bir yerde herhangi

bir anda iletişim kurma olanağı sağlıyor. Kablosuz haberleşme teknolojileri kablo

kullanımını 5 kat azaltmaktadır. Bu sistem belli bir mesafede hareket özgürlüğü

sağladığından sabit duran veya hareketli bir üründen bilgi almak/göndermek

kablosuz haberleşme için büyük bir avantajdır. Tarihte ilk fikir, bilgisayar ve

çevresindeki elektronik ürünlerin birbirleriyle kablosuz haberleşmesini sağlamaktı.

Daha sonra bu düşünce genişledi ve daha da büyük alanlarda kullanılması hedeflendi.

Dar alan kablosuz haberleşme sistemleri özellikle askeri alanda, tıpta, oto sanayide ve

AVM’lerde kullanılmaya başlamakta ve gün geçtikçe kullanım alanları artmaktadır.

Bu sistemdeki temel amaç, düşük güç harcayarak en az 10 metrelik bir alanda kablo

olmaksızın güvenli bir haberleşme ağı kurmaktır. KAYNAK [2]

7

### 1.4. A.4: Kablosuz Haberleşmenin Bazı Türleri

Bugüne dek birçok firma tarafından kablosuz haberleşme modellerini üretmek

adına birkaç çeşit model üretilmiştir. 3G ve 4G, WI-MAX, Bluetooth ve WiFi

gibi teknolojiler en popüler olanlarıdır. PAN’ ler için geçtiğimiz senelere kadar

Bluetooth ve WiFi olmak üzere iki ana teknoloji bulunmaktaydı. Ancak her

sistemin kolaylıkları ve yenilikleri olmasına rağmen bazı istekleri karşılayamazlar.

PAN ağlarından biri olan ZigBee 1999 yılında FireFly çalışma grubu tarafından

tasarlamaya başlamıştır. Bu sayede bazı istekler karşılanmıştır.

8

### 1.5. A.5: Bluetooth (IEEE 802.15.1)

Bluetooth adını eski Danimarka Kralı Harald Blataad’ tan almıştır. Bluetooth genel

olarak bina içi kablosuz ağ sistemi olarak tanımlanabilir. Tasarlanış amacı kısa

mesafelerde düşük güç tüketmek suretiyle diğer komşu elektronik cihazlarla bağlantı

kurarak veri alışverişinde bulunmaktır. Bluetooth birbirini kapsam alanında görme

şartını ortadan kaldırmış olmasına rağmen güvenlik problemi ortaya çıkmış ve bu

kamsam alanı içindeki sistemi haberleşecek olan sitemlerin girişim ve bayılmadan

dolayı bağlantı kopma problemleri 6 oluşmuştur. Aynı zamanda Bluetooth sistemi

kapsam alanı dışındaki sistemlerle de girişim oluşturabilmektedir.

### 2. BÖLÜM

B: ARDUİNO

Arduino kullanımı ilk başta pek az kişi tarafından bilinmekteydi. kökenleri ise

Wiring ve Processing projelerine dayanmaktadır. Henüz programlama deneyimi

olmayan kişilere programlamayı öğretebilmek amacıyla processing programlama

dili ve geliştirme ortamı oluşturulmuştur. Teknik bilgisi az olan insanlara bilgi

besleme adına da kolaylık sağlayan arduino, çevresiyle etkileşim içinde olan interaktif

nesneler oluşturmak isteyen tasarımcılar için de büyük kolaylık sağlamaktadır.

Arduino bir Giriş/Çıkış kartı ve Processing dilinin uygulamasını da dahilinde

bulunduran bir fiziksel programlama platformudur. Arduino bilgisayar üzerinde

çalışan yazılımlarda kullanıldığı gibi tek başına çalışan interaktif nesneler oluşturmak

için de kullanılabilir.

Arduino’ nun neden bu kadar çok tercih edildiğini maddeler halinde gösterirsek:

- Windows, Linux, Mac gibi bütün platformlarda çalışabilen geliştirme ortamı ve

sürücülerinin kurulumu çok kolay olmaktadır.

- Zengin bir kütüphane barındırdığından Birçok karmaşık işleme kolaylık

sağlayabilmektedir.

- İçerisinde aktarılan kodlar/programlar oldukça hızlı çalışmaktadır.
- Başka donanımlarla da çalışabilmesi adına ek donanımlar içermektedir. Bu karta

bağlanamayan sensör çeşidi yok desek yeridir.

- Benzer diğer devre kartlarına kıyasla fiyatı oldukça uygundur.
- Açık kaynak kodlu olması kullanmak isteyen herkesin özgürlüğine olanak

sağlamaktadır. Misal bir eğitim kurumu Arduino için lisans parası ödemeden

rahatça kullanabilir. KAYNAK [5],[6]

10

### 2.1. B.1: Arduino Çeşitleri:

1. Arduino Uno
2. Arduino Nano
3. Arduino Mega
4. Arduino Mini ve Mini Pro
5. Arduino Bluetooth
6. Arduino Lilypad 20
7. Arduino Leonardo
8. Arduino Adk
9. Arduino Ethernet

11

### 2.2. B.1.1: KULLANILAN MALZEMELER

Arduino Nano x 1 ————————————— 9v Pil x 1

M2x10 Vida 30 civarı ———————————- M5x20 Vida x3

MG90s - Servo Motor x 3 —————————– Makaron Kablo

HC-05 Bluetooth Modül x 1 ————————– LM2596 Voltaj Regülatörü x1

3D Printer Taret Kalıbı ——————————– Dirençler (10k, 330, 680) x3

FR207 Doğrultucu Diyot x 1 ————————– Super Glue + Spray

Jumper Kablo ——————————————— 2.1x5.5mm Jak Fişi x1

RFP30N06LE mosfet x1 ——————————– Type 130 DC Motor x2

1.5mm Metal Çubuk x1 ——————————— Dupont Konnektörler


Şekil 2.1. Not: Projede Kullacağım Malzemeler (Bazı parçaları eksik ve 3D kalıp hariç görüntüsüdür.)

12

B.2: Arduino Uno

Geliştirilen birçok projede kullanılan en popüler devre kartıdır. Üzerinde birkaç

donanım barındırmaktadır. Bunlar: Atmega328 mikrodenetleyici, 16 MHz kristal,

güç regülatörü, USB bağlantı portu, gibi bileşenler bulunuyor. Üzerindeki USB

dönüştürücü sayesinde hem gerekli kodlar aktarılabilmekte hem de bilgisayar

ile iletişim kurulabilmektedir. Kart, üzerindeki fiş jakı sayesinde adaptör

tarafından veya üzerindeki USB portu sayesinde kurulan USB bağlantısı tarafından

beslenebilmektedir. Arduino Uno kartının ön ve arka görünümü sırasıyla, Şekil 2 ve

Şekil 3’de gösterilmiştir.

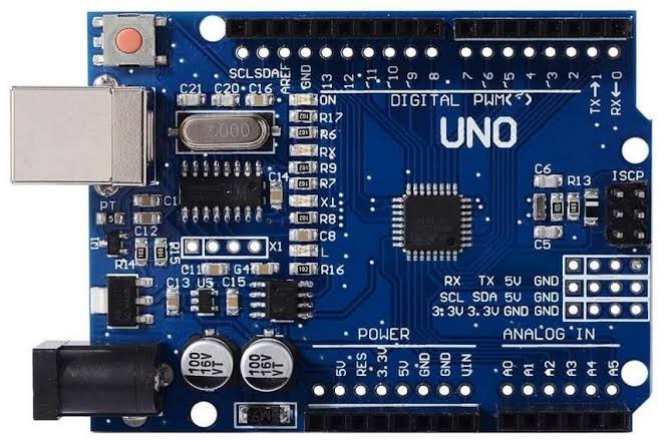
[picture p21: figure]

Şekil 2.2. Arduino Uno (Klon) kartının ön görünümü


Şekil 2.3. Arduino Uno (Klon) kartının arka görünümü

13

B.3: Servo Motor

Servo motorlar çoğu projenin hareketini sağlamakta ve olmazsa olmazlardandır.

CNC’lerde, model uçaklarda, RC arabalarda, 3D Printerlarda ve küçük güçteki

birçok robot uygulamalarında kullanılmaktadır. Servo motor içerisinde geri besleme

potansiyometresi, DC elektrik motoru, DC motor konum kumanda elektroniği ve

planetar dişli sistemi bulunmaktadır. Bu motorlar projemde tasarlanan taretin

gövde, baş ve tetikleme hareketlerini gerçekleştirmek amacıyla kullanılacaktır. Servo

motorun blok diyagramı, projede kullanılan modeli ve devre şeması sırasıyla, Şekil

4, Şekil 5 ve Şekil 6’da gösterilmiştir.

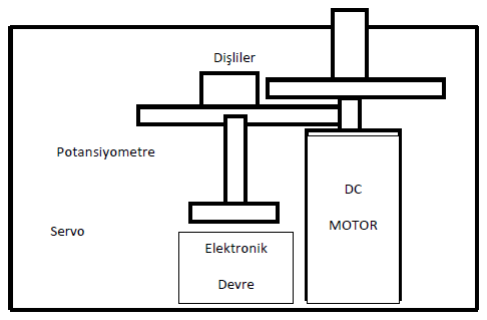
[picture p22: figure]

Şekil 2.4. Servo motorların genel iç blok diyagramı


Şekil 2.5. Projede Kullanılan MG90s Servo

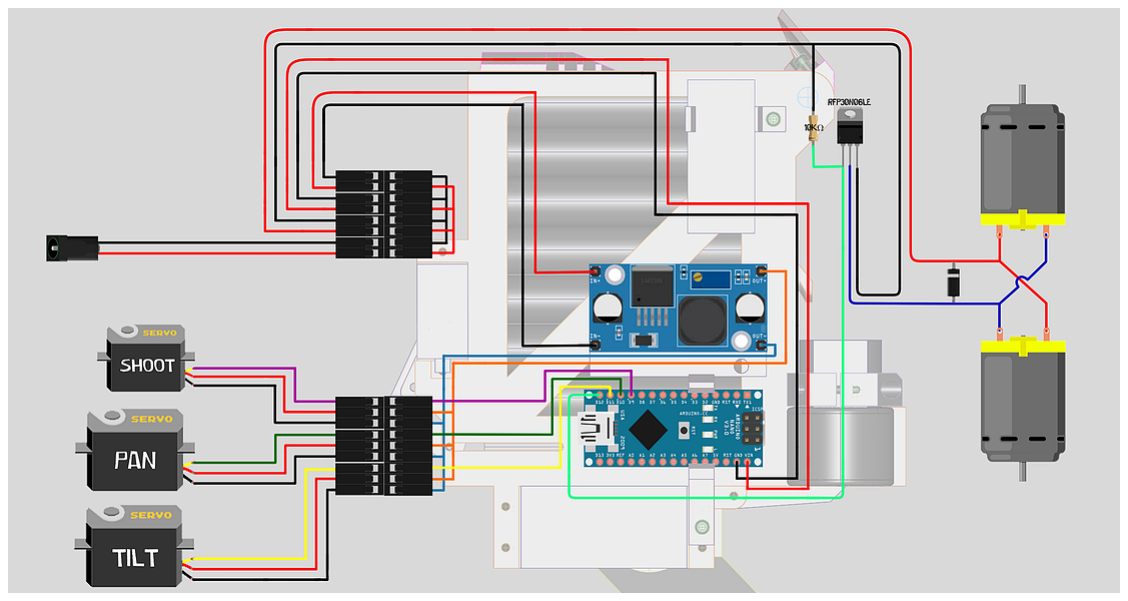
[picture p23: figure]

Şekil 2.6. Servo Motorların Projedeki Devre Şeması

14

B.3.1: TEKNİK ÖZELLİKLER:

MG90s Servo Motor Özellikleri:

- Çalışma tork: 2 kg/cm
- Hızı: 0.11 sn/60◦
(4.8 V)
- Çalışma aralğığı: 4.8 - 6.0 V
- Çalışma sıcaklığı: 0◦

-55◦

- Ölü bant ayarı: 5 mikrosaniye
- Dönme açısı: 180 derece
- Çalışma gerilimi: 4.8 V - 6.0 VDC
- Yapısal Malzeme: bakır metal diş, çekirdeksiz motor, çift bilyalı rulman
- Boyutu: 23 x 12x 29 mm

15

B.4: HC-05 Bluetooth Modül

HC-05 Bluetooth modülü, kablosuz seri haberleşme projeleri için yapılmıştır. Bu

modül bluetooth 2.0’ı destekleyen, 2.4GHz frekansında haberleşme yapılmasını

sağlar. Haberleşme esnasında açık alanda yaklaşık 10 metre haberleşme mesafesine

sahiptir. Modülün haberleşme bağlantısı serial yani UART olduğundan kolay ve

hızlı bir kullanımı vardır. Üzerinde bulunan RX ve TX pinleri sayesinde iletişim

sağlanır. Bu pinler kullanılacak olan devre kartınının sırasıyla TX ve RX pinlerine

bağlanır. Ayrıca bu pinler yardımıyla AT komutlarını kullanarak modülün isim,

şifre,baud rate değeri, gibi çeşitli özellikleri değiştirebilir. KAYNAK [3]

Projede ise bu modül kablosuz haberleşme için kullanılmaktadır. Bilgisayar veya

mobil üzerinden alınan analog veriler bu modül sayesinde tarete aktarılmaktadır.

Bu sayede kullanıcı tarafından yapılan hareketleri anlık olarak taret üzerinde de

gözlemleyebiliriz. Bluetooth modül Şekil 7de gösterilmiştir.


Şekil 2.7. Projede Kullanılan HC-05 Bluetooth Modülü

Dikkat: HC-05 Bluetooth modülü devre kartındaki 3.3V pinine bağlantı yapılarak

veya uçları arasında dirençler bağlayarak çalıştırılması gerekmektedir. HC-06

Bluetooth modülü ise 5V pinine bağlantı yapılarak veya yine direnç bağlanarak

çalıştırılmalıdır.

Bilgi: Kodları hatasız bir şekilde Arduino’ya aktarabilmek için Arduino üzerindeki

RX ve TX pinlerine bağlı kabloları aktarma işleminden önce sökmek gerekiyor. Bu

işlem yapılmazsa kod aktarımı sırasında portların meşgul olduğuna dair hata alırız.

16

B.4.1: TEKNİK ÖZELLİKLER:

- Çalışma Gerilimi: 3.3 V - 5 V,
- Akım: 50 mA,
- Bluetooth Protokolü: Bluetooth 2.0+EDR,
- Haberleşme frekansı 2.4GHz,
- Hassasiyet: ≤-80 dBm,
- Çıkış Gücü: ≤+4 dBm,
- Asenkron Hız: 2.1 MBps/160 KBps,
- Senkron Hız: 1 MBps/1 MBps,
- Güvenlik: Kimlik Doğrulama ve Şifreleme,
- Boyutları: 43 x 16 x 7mm,

HC-05 Modülünün devre şeması Şekil 8’de gösterilmiştir.


Şekil 2.8. HC-05 Modülünün Bağlanma Şekli (Fritzing)

17

B.5: 3D Taret Modeli

Taretin baskısı 3D yazıcılar vasıtasıyla PLA+ Filament kullanılarak yapıldı. Kendi

oluşturmuş olduğum 3D modelleri ile Github üzerindeki üyerlerin modellerini mix

ederek aşağıdaki modelleri elde etmiş oldum. 3D modeli oluşturmak için Blender

programını kullandım. Taretin 3D modelleri Şekil 9’da gösterilmiştir. KAYNAK [1]

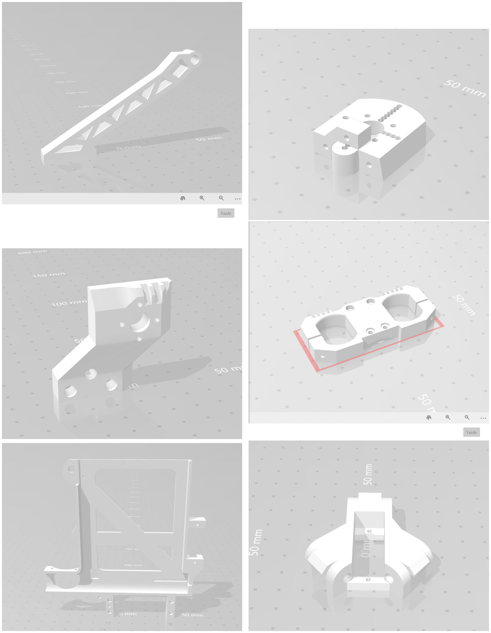
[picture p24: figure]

Şekil 2.9. Taret 3D Model Örnekleri

18

C: Programlama Aşaması

Tüm devrelerin montajı tamamlandı ve projenin programlama aşamasına geçildi.

Bu aşamada ilk önce fare hareketlerinin analog değerleri serial monitörden okunarak

hassasiyet değerlendirmesi maksatıyla tam değerleri bulundu. Arduino NANO devre

kartı ise okunan değerleri projede kullanılan servo motorlara dikey ve yatay açısal

bilgileri gönderecek şekilde programlandı. Tüm kodlamalar Arduino IDE programı

vasıtasıyla Bilgisayardan USB kablo ile Arduino NANO Mikrodenetleyicisine

aktarıldı.


19


20

21


22


23

D: SONUÇLAR

Yazılım ve Elektronik alanlarında yapılan yeni projeler ve devam eden çalışmaların

en önemlileri insan sağlığını koruyacak türde veya global teknolojiye ayak uydurarak

askeri ya da endüstriyel alanlarda gelişime açık olanlarıdır. Bu fikirle başladığım

projeyi tamamlamak için amaçladığım gibi tareti kontol eden kişinin verdiği

komutları veri kaybı olmadan tarete ulaşmasını sağlayabilmek vasıtasıyla tasarlanan

taretin hedefe isabetli atışlarını gerçekleştirdim. Bu işlemin kullanıcı ve taret

arasında kablosuz haberleşme ile sağlandığını vurgulamak gerekir.

Bu projeyi gerçekleştime aşamalarında birçok sıkıntıyla karşılaştım. İlk karşılaştığım

sıkıntı satın almış olduğum arduino nano kartında arıza olmasıydı. Bu kartın

hatalı olduğunu anlatıktan sonra yenisi temin ettim. ancak bu bozuk kartla işlem

yapmaya kalkarken sanırsam hc-05 bluetooth modülümün de hasar aldığını farkettim

ve onu da değiştirmek zorunda kaldım. Projede kullanılmasını uygun gördüğim

FR207 hızlı diyot ve rfp30n06le mosfeti birçok yerde aradım ancak bulamadım.

diyotun özellikleri 2A 100V değerlerini gösterirken mosfet ise 30A 60V değerlerini

göstermekte. Ancak değindiğim gibi bu modülleri temin edemedeğimden bunların

yerine BY298 hızlı diyot (2A 400V) ve ırfp250n mosfet (30A, 200V) modüllerini

kullanmaya karar verdim. Bu modüller DC motorlara bağlantı kurduğundan,

muhtemelen bu karar değişimden dolayı proje testi esnasında asıl büyük sıkıntıyı

burada yaşadım. DC motorların güç kaçağı veya geri besleme gibi sıkıntılardan

olsa gerek devreyi stabil tutamadım. bu kısım beni gerçekten çok uğraştırdı. İlk

başlarda sıkıntının ne olduğunu da tam anlayamadım. En sonunda Voltaj dengesini

sağlayarak devreyi stabil tutabildim.

Projenin sunumunu ayrı şekilde temin edeceğimden bu final tezine ekleme

yapabileceğim kodlama, sonuç ve yorumlamalardan başka birşey kalmıyor. Zaten

projenin son halini yazımdan çok videodaki anlatıma döktüm. Eminim yeterli

gelecektir.

24

E: YORUMLAR VE DEĞERLENDİRME

Bu tarz robotik projeleri yapmaktan gerçekten keyif alıyorum ve kendimi bu alana

yönelik geliştirmek istiyorum. Yaptığım proje ve bundan öncekilerin de bana

katkısının büyük olduğunu düşünüyorum. Başlarda elektronik komponentler ve

devre kartları üzerine pek bilgim yoktu ancak şuan bu tarz projeleri bitirmemin,

bunları özellikle de tek başıma yapmanın bana katkısı büyük oluyor. Tüm

araştırmalar ve analizler bana kalıyor ve bu sayede bilgi edinme hızım gayet hızlı

ilerliyor. Ülkemizde hala gelişmekte olan robotik alan projeleri yurtdışında bazı

bölgelerde fazlasıyla gelişmiş durumda ve imkanım olursa kenidimi bu firmalarda

görmeyi isterim. Bunu da hedeflemek adına kendi gelişimimi bu karara göre

yönlendireceğim.

25

KAYNAKLAR

[1]. Github Users, Multi persons, Arduino Turret, Available: https://github.com/

[2]. The Extendedsystem website. Available: http://www.extendedsystems.com/

[3]. Haartsen, J. C., The Bluetooth Radio System, IEEE Personal Communications

[4]. Çamoğlu, D., Kontrollü Robotik, Dikeyeksen Yayıncılık, Şubat 2011.

[5]. Taşdemir, C., Arduino, Dikeyeksen Yayın Dağıtım, Yazılım ve Eğitim Hizmetleri

San. ve Tic. Ltd. Şti., İstanbul, 2012.

[6]. D. İbrahim, PIC Mikrokontrolör Robot Projeleri, Bileşim Yayıncılık Fuarcılık

ve Tanıtım Hizmetleri A.Ş., İstanbul, Türkiye, 2005.

26

EK 3. Standartlar ve Kısıtlar Formu

Erciyes Üniversitesi Mühendislik Fakültesi Bilgisayar Mühendisliği

STANDARTLAR VE KISITLAR FORMU

### 1. Projenizin tasarım boyutu nedir?

Plastik mermi kullanacak şekilde Minimizal bir boyutta olup ergonomik olması

hedeflenmektedir. Kullanımı ve gerçekleştirilmesi karmaşık olmayacak. Savunma

sanayide kullanılabilir olup, birçok askeri ve manevi ihtiyacı karşılayacaktır.

### 2. Üniversite eğitim süreci boyunca girdiğiniz derslerden edindiğiniz

hangi deneyim ve bilgileri kullandınız?

Temel olarak Arduino programını kullanmamıza olanak sağlayan elektronik

derslerinden ve gömülü sistemlerden projenin devresini oluşturmakta zorluk

çekmedim. Ayrıca mikroişlemciler dersini almamın bana bu proje üzerinde araştırma

kolaylığı sağladığı da aşikardır.

### 3. Projenizde bir mühendislik sorununu kendi yöntemlerinizle formüle

edip, çözüm sağladınız mı?

Yorumlama ve Değerlendirme kısmında bahsettiğim gibi bu kısım hakkında şuan

için verebileceğim bir bilgi yok.

### 4. Dikkate aldığınız esas kısıtlar nelerdir?

a) Teknoloji

Sürekli gelişen teknolojiye her zaman güncel kalmak kimseyi geride bırakmaz. Bu

izlenimle projenin mevcut teknolojiye ayak uydurması ve başka projelere de ilham

kaynağı olması hedeflenmektedir. Her yeni çıkan teknolojiler izlenmeli ve mümkün

olan en yeni parçalarla ürünü sunmak gerekmektedir.

27

b) Ekonomi

Projenin üretim maliyeti, projenin hayata geçmesi ve zarar edilmemesi açısından

oldukça önemli bir faktördür. Projede kullanılacak olan parçaların performansı ve

fiyatı incelenerek fiyat/performans oranları çıkarılmaya çalışılmıştır.

c) Çevre sorunları:

Proje düşük enerji tüketimi ile çevre dostu olduğundan ve çevreye verebileceği

herhangi bir zararı bulunmadığı için oldukça kullanışlıdır.

d) Üretilebilirlik:

Projede kullanılan malzemelerin satış fiyatları oldukça uygundur. Böylelikle bu

çaplı minimizal (aynı zamanda deneysel) bir projenin hayata geçirilmesi için büyük

bir imkân sağlanıyor. Projeyi dinamik ve performanslı hale getirerek endüstriyel

anlamda seri üretime geçilme imkânı sağlanmalıdır. Şuanda da birkaç benzer örneği

mevcuttur.

e) Sürdürülebilirlik:

Günümüz çağında Mikrodenetleyici kontrollü kablosuz sistemler, yeni gelişmekte

olan bir sektördür. Mikroişlemcilerin, entegre parçaların, transistörlerin ve

sensörlerin gelişmesiyle ilerde çok daha gelişeceğini tahmin etmek zor olmasa gerek.

Proje kolay geliştirilebilir olduğundan bu imkana olanak sağlıyor. Ayrıca farklı proje

ve sistemlerle ortak noktalarda birleştirilebilecek bir projedir.

f) Sağlık:

Robot elin üretimi için kullanılacak olan PLA+ Filamentin bileşenleri mısır besi

dokusundan elde edilen nişasta ve şeker pancarı gibi bitkisel, yenilebilen ürünlerden

elde edilir. Bu nedenle doğaya hiçbir şekilde zarar vermez. Isı ile oluşabilecek sağlığa

zararlı ve kötü koku salınımı yapan gazlar ortaya çıkarmaz.

g) Güvenlik:

Projenin devresindeki tüm bileşenler voltaj regülatörü + trimpot ile dengelenmiş

olup 5V ile çalışmaktadır ve hiçbir şekilde güvenlik açığı teşkil etmezler.

28

ÖZGEÇMİŞ

KİŞİSEL BİLGİLER

Adı, Soyadı | : Alper Burak PUSAR
Uyruğu | : Türkiye (T.C.)

Doğum
Tarihi ve
Yeri

: 24.07.1995 - ANKARA

Telefon | : 0 544 247 9350
Belgegeçer | : 0 544 247 9350
E-posta | : 1030520446@erciyes.edu.tr
Adres | : Akpınar Mah.
4. Altın Sok. No-10 Daire:4
| 16010, Osmangazi BURSA TÜRKİYE

EĞİTİM

Derece | Kurum | Mez.Yılı
Lise | Ali Karasu Lisesi, BURSA 13
Ortaokul Akpınar İ.Ö.O, BURSA | 09

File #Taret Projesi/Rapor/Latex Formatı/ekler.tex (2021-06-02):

\textbf{EK 3. Standartlar ve Kısıtlar Formu}
\label{CH:BolumEkler3}

\begin{figure}[H]
	
    \label{fig:EruLogoDM} \centering Erciyes Üniversitesi Mühendislik Fakültesi Bilgisayar Mühendisliği
\end{figure} 

\textbf{STANDARTLAR VE KISITLAR FORMU}
\\ \hline 

\textbf{1. Projenizin tasarım boyutu nedir?}

 	Plastik mermi kullanacak şekilde Minimizal bir boyutta olup ergonomik olması hedeflenmektedir. Kullanımı ve gerçekleştirilmesi karmaşık olmayacak. Savunma sanayide kullanılabilir olup, birçok askeri ve manevi ihtiyacı karşılayacaktır.
    
\textbf{2. Üniversite eğitim süreci boyunca girdiğiniz derslerden edindiğiniz hangi deneyim ve bilgileri kullandınız?}

	Temel olarak Arduino programını kullanmamıza olanak sağlayan elektronik derslerinden ve gömülü sistemlerden projenin devresini oluşturmakta zorluk çekmedim. Ayrıca mikroişlemciler dersini almamın bana bu proje üzerinde araştırma kolaylığı sağladığı da aşikardır.
    
\textbf{3. Projenizde bir mühendislik sorununu kendi yöntemlerinizle formüle edip, çözüm sağladınız mı? }

	Yorumlama ve Değerlendirme kısmında bahsettiğim gibi bu kısım hakkında şuan için verebileceğim bir bilgi yok.
    
\textbf{4. Dikkate aldığınız esas kısıtlar nelerdir? }

a) Teknoloji

	Sürekli gelişen teknolojiye her zaman güncel kalmak kimseyi geride bırakmaz. Bu izlenimle projenin mevcut teknolojiye ayak uydurması ve başka projelere de ilham kaynağı olması hedeflenmektedir. Her yeni çıkan teknolojiler izlenmeli ve mümkün olan en yeni parçalarla ürünü sunmak gerekmektedir.
    
 b) Ekonomi
 
	Projenin üretim maliyeti, projenin hayata geçmesi ve zarar edilmemesi açısından oldukça önemli bir faktördür. Projede kullanılacak olan parçaların performansı ve fiyatı incelenerek fiyat/performans oranları çıkarılmaya çalışılmıştır. 

c) Çevre sorunları: 

	Proje düşük enerji tüketimi ile çevre dostu olduğundan ve çevreye verebileceği herhangi bir zararı bulunmadığı için oldukça kullanışlıdır.
    
d) Üretilebilirlik: 

	Projede kullanılan malzemelerin satış fiyatları oldukça uygundur. Böylelikle bu çaplı minimizal (aynı zamanda deneysel) bir projenin hayata geçirilmesi için büyük bir imkân sağlanıyor. Projeyi dinamik ve performanslı hale getirerek endüstriyel anlamda seri üretime geçilme imkânı sağlanmalıdır. Şuanda da birkaç benzer örneği mevcuttur.
    
e) Sürdürülebilirlik:

	Günümüz çağında Mikrodenetleyici kontrollü kablosuz sistemler, yeni gelişmekte olan bir sektördür. Mikroişlemcilerin, entegre parçaların, transistörlerin ve sensörlerin gelişmesiyle ilerde çok daha gelişeceğini tahmin etmek zor olmasa gerek. Proje kolay geliştirilebilir olduğundan bu imkana olanak sağlıyor. Ayrıca farklı proje ve sistemlerle ortak noktalarda birleştirilebilecek bir projedir. 
    
f) Sağlık: 

	Robot elin üretimi için kullanılacak olan PLA+ Filamentin bileşenleri mısır besi dokusundan elde edilen nişasta ve şeker pancarı gibi bitkisel, yenilebilen ürünlerden elde edilir. Bu nedenle doğaya hiçbir şekilde zarar vermez. Isı ile oluşabilecek sağlığa zararlı ve kötü koku salınımı yapan gazlar ortaya çıkarmaz.
    
 g) Güvenlik: 
 
	Projenin devresindeki tüm bileşenler voltaj regülatörü + trimpot ile dengelenmiş olup 5V ile çalışmaktadır ve hiçbir şekilde güvenlik açığı teşkil etmezler.

\clearpage

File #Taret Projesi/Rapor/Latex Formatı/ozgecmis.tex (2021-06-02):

%%%%%%%%%%%  1. Yazar Özgeçmiş %%%%%%%%%%%%%%
\textbf{KİŞİSEL BİLGİLER}\\

\renewcommand{\arraystretch}{1.5}
\begin{table*}[h]
	\begin{tabular}{p{2.8cm}ll}
	\textbf{Adı, Soyadı }&: & Alper Burak PUSAR \\
	\textbf{Uyruğu }&: & Türkiye (T.C.)\\
	\textbf{Doğum Tarihi ve Yeri}&: & 24.07.1995 - ANKARA \\
	\textbf{Telefon}& : & 0 544 247 9350 \\ 
	\textbf{Belgegeçer} & : & 0 544 247 9350 \\ 
	\textbf{E-posta} & : &  1030520446@erciyes.edu.tr \\ 
	\textbf{Adres} & : & Akpınar Mah.  \\ 
		&  & 4. Altın Sok. No-10 Daire:4  \\ 
	 & & 16010,  Osmangazi BURSA TÜRKİYE\\
	\end{tabular}
\end{table*}

%\vspace*{10mm}

\textbf{EĞİTİM}\\

\begin{tabular}{lll}
	\textbf{Derece} & \textbf{Kurum} & \textbf{Mez.Yılı}  \\ 
	Lise & Ali Karasu Lisesi, BURSA  & 13  \\ 
	Ortaokul & Akpınar İ.Ö.O, BURSA  & 09 \\

\end{tabular}

\clearpage

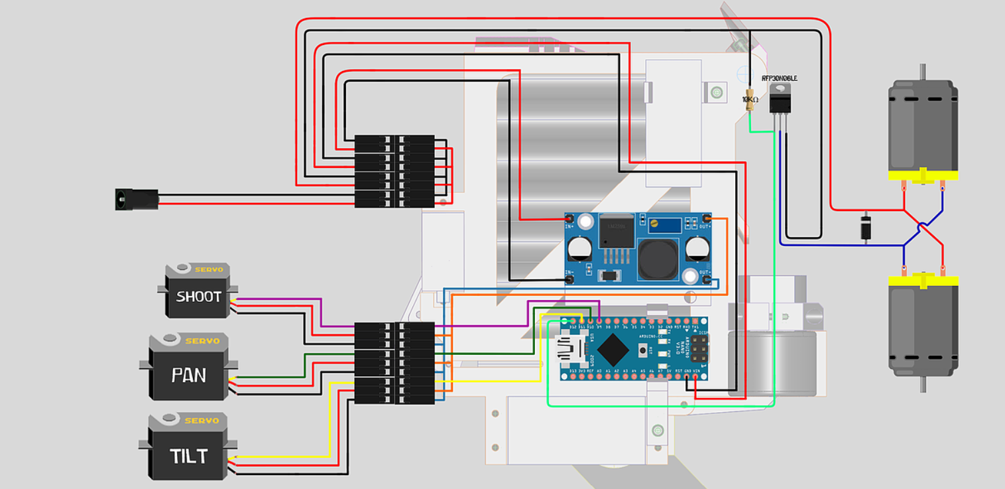
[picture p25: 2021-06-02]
#Taret Projesi/Kodlar ve Bağlantı Şemaları/HC-05 Hariç Tüm Bağlantılar.png

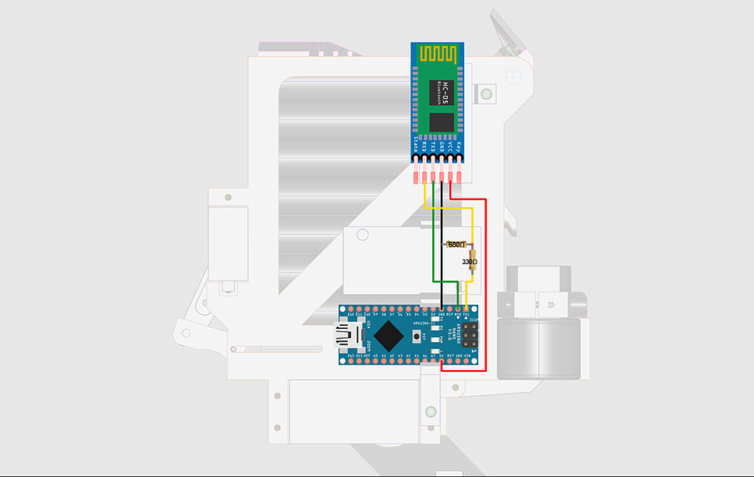
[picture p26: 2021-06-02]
#Taret Projesi/Kodlar ve Bağlantı Şemaları/HC-05 Bağlantısı.png

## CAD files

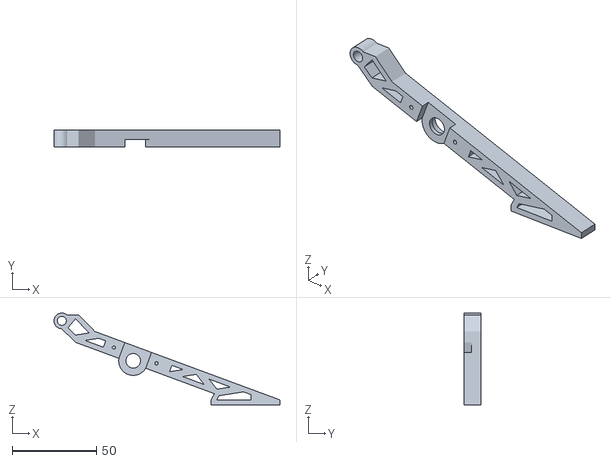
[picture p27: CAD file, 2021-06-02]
#Taret Projesi/3D Tasarım/littlefrenchkev's stl parts/bacak/long_leg_round.stl
133.8 x 10.0 x 54.5

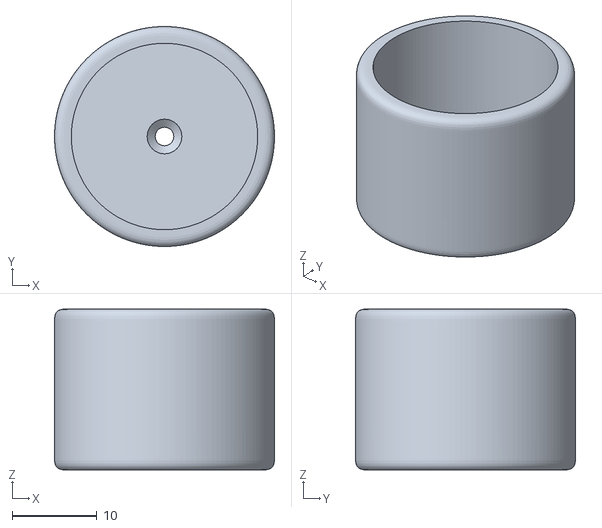
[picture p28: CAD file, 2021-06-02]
#Taret Projesi/3D Tasarım/littlefrenchkev's stl parts/genel parçalar/Roller.stl
26.0 x 26.0 x 19.0

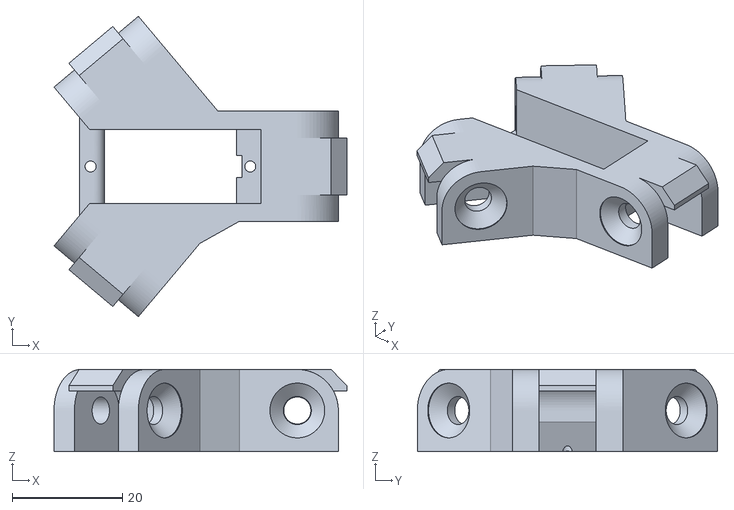
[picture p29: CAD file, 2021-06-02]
#Taret Projesi/3D Tasarım/littlefrenchkev's stl parts/MG90 panaromik parça/base_MG90.stl
53.2 x 54.5 x 14.9

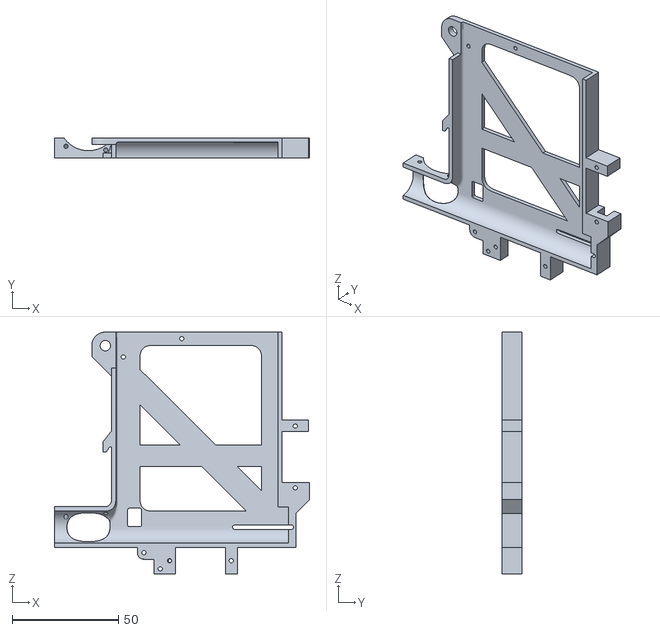
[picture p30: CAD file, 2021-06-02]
#Taret Projesi/3D Tasarım/littlefrenchkev's stl parts/MG90 tilt parçaları/Barrel_R_MG90.stl
119.8 x 9.50 x 113.6

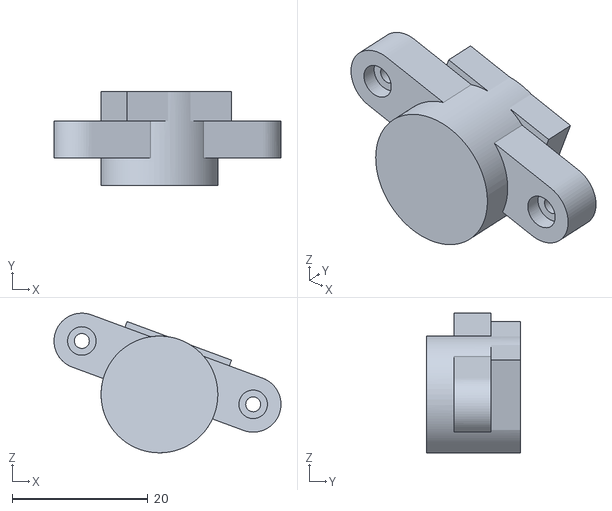
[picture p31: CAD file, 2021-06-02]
#Taret Projesi/3D Tasarım/littlefrenchkev's stl parts/bacak/long_leg_cap_round.stl
33.4 x 13.8 x 20.6

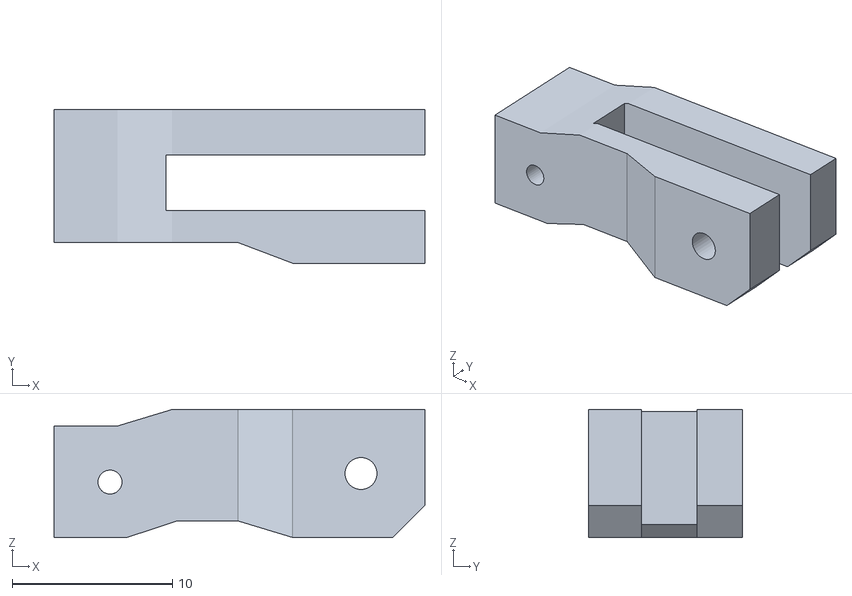
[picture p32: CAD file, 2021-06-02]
#Taret Projesi/3D Tasarım/littlefrenchkev's stl parts/genel parçalar/Recoil_arm_2.stl
23.2 x 9.60 x 8.00

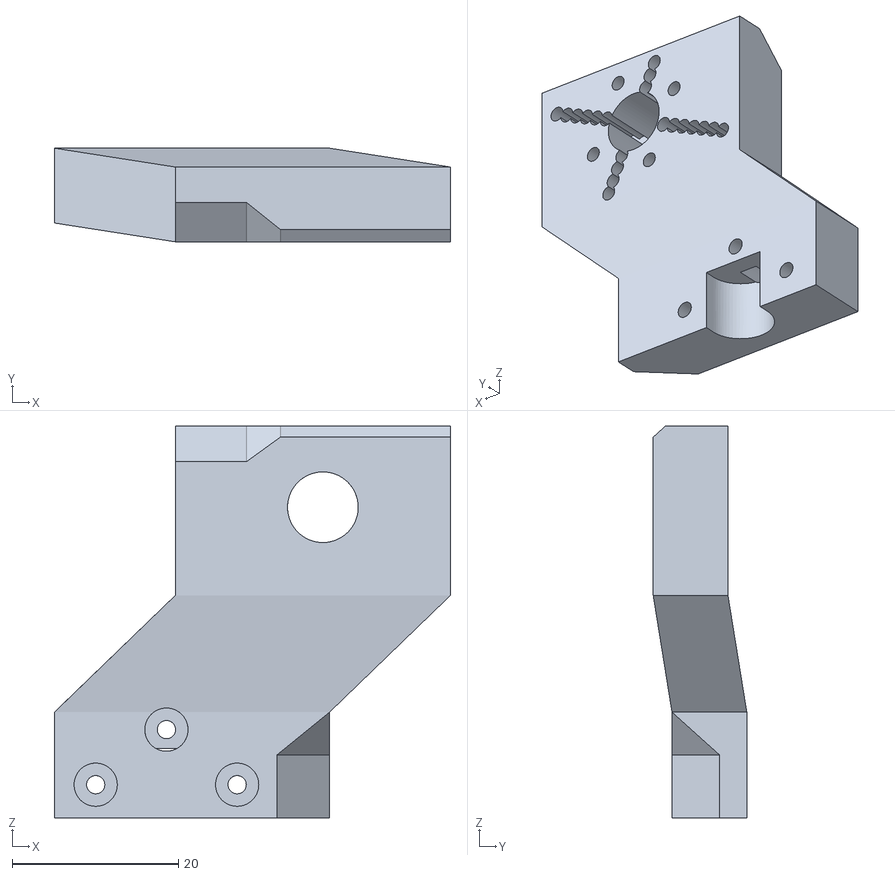
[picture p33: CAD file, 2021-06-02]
#Taret Projesi/3D Tasarım/littlefrenchkev's stl parts/MG90 tilt parçaları/Tilt_bracket_top_MG90.stl
47.6 x 11.3 x 47.1

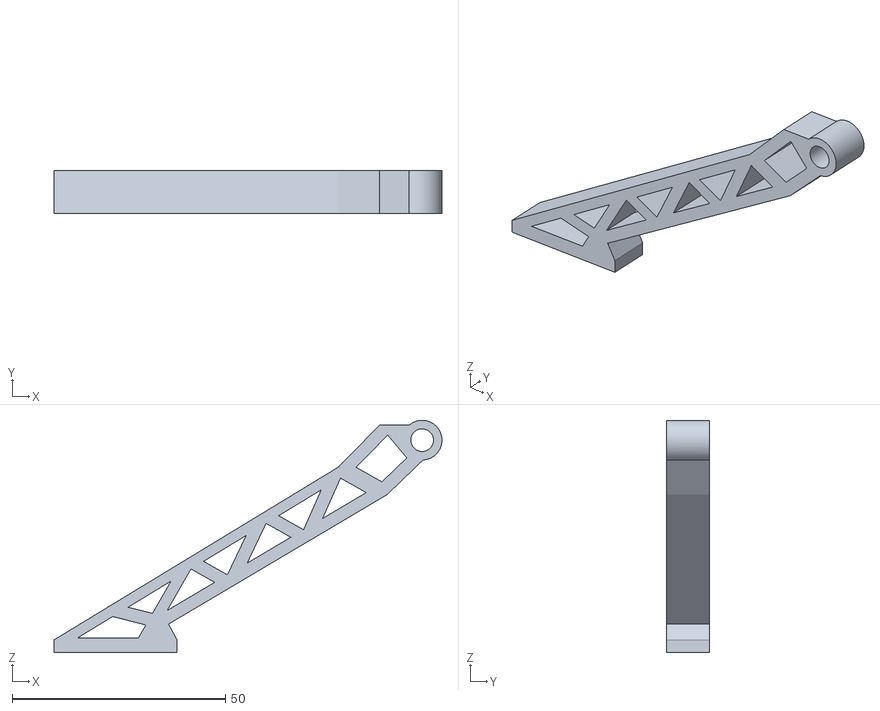
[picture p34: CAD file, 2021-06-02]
#Taret Projesi/3D Tasarım/littlefrenchkev's stl parts/genel parçalar/short_leg.stl
90.9 x 10.0 x 54.5

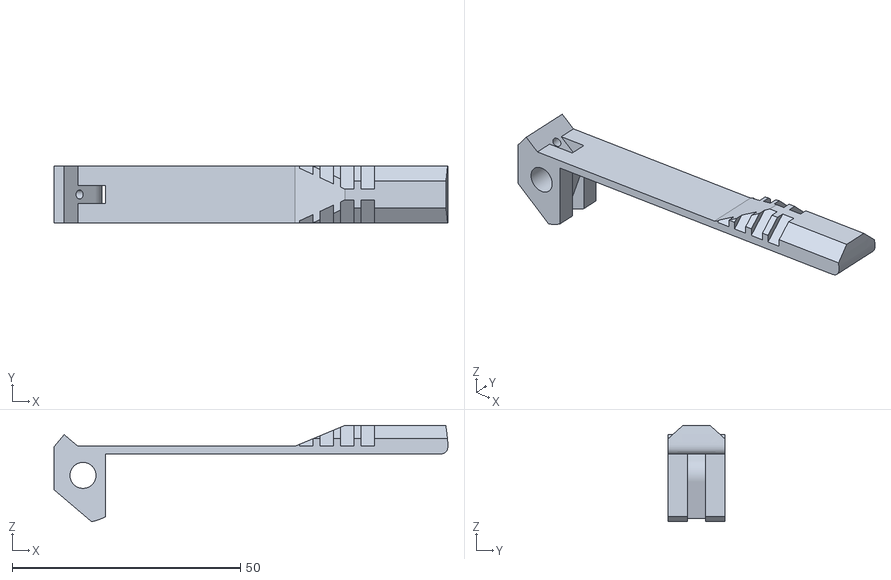
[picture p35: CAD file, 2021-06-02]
#Taret Projesi/3D Tasarım/littlefrenchkev's stl parts/genel parçalar/Top_cap.stl
86.3 x 12.4 x 21.1

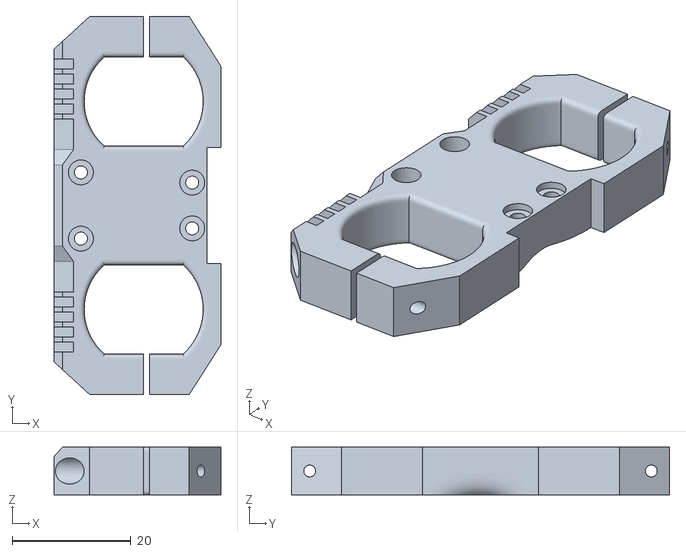
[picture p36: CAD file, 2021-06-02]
#Taret Projesi/3D Tasarım/littlefrenchkev's stl parts/genel parçalar/Motor_bracket_3mm.stl
28.1 x 63.6 x 8.00

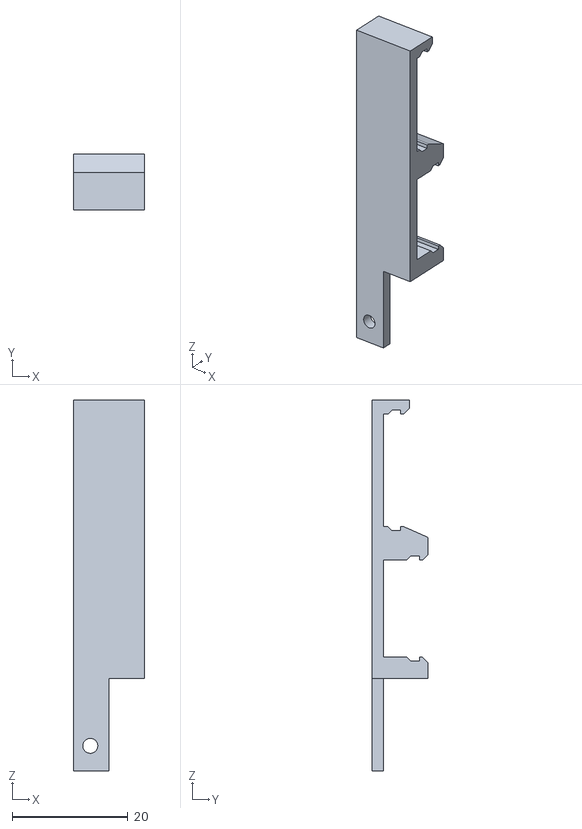
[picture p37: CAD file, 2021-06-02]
#Taret Projesi/3D Tasarım/littlefrenchkev's stl parts/genel parçalar/Arduino_bracket.stl
12.3 x 9.75 x 64.2

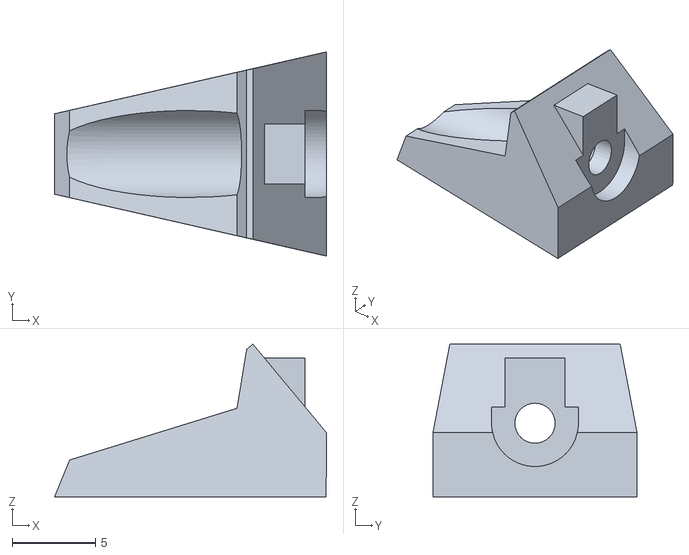
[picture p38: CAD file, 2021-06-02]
#Taret Projesi/3D Tasarım/littlefrenchkev's stl parts/genel parçalar/band_lock.stl
16.3 x 12.2 x 9.17

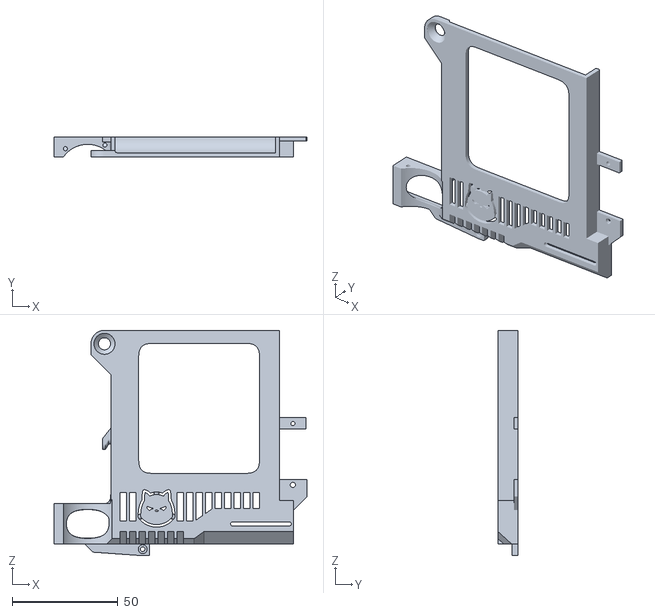
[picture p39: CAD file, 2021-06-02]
#Taret Projesi/3D Tasarım/littlefrenchkev's stl parts/genel parçalar/Barrel_L.stl
119.8 x 9.50 x 106.7

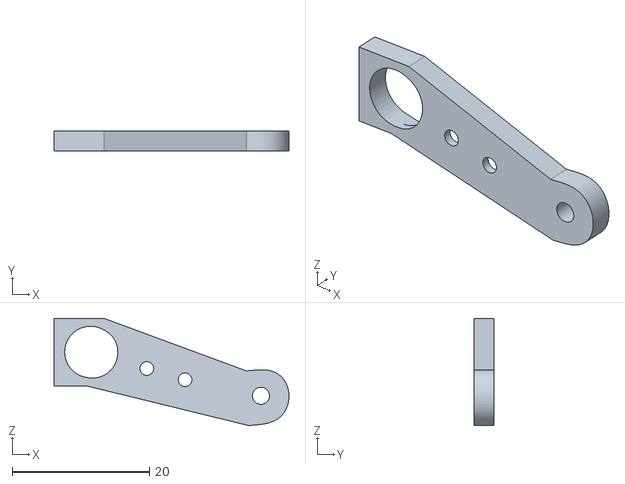
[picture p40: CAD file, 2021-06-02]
#Taret Projesi/3D Tasarım/littlefrenchkev's stl parts/genel parçalar/Recoil_arm.stl
34.3 x 2.96 x 15.6

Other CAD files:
#Taret Projesi/3D Tasarım/littlefrenchkev's stl parts/genel parçalar/Bluetooth_bracket.stl
#Taret Projesi/3D Tasarım/littlefrenchkev's stl parts/genel parçalar/Tilt_bracket_bottom.stl

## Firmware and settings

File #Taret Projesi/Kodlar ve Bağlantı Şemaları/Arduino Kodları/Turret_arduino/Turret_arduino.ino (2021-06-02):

#include <Servo.h>

// Alper Burak PUSAR - 1030520446

//-----Servoları ve değişkenleri bildirme

Servo pan_servo;
Servo tilt_servo;
Servo recoil_servo;

const byte tilt_limit_1 = 65;
const byte tilt_limit_2 = 180;
const byte pan_limit_1 = 0;
const byte pan_limit_2 = 180;
const byte recoil_rest = 180;    // Hareketsizken servo açısı
const byte recoil_pushed = 125;  // Mermiyi itmesi için servonun ulaşması gereken açı

//-----Seri veri işleme ile ilgili değişkenler
byte byte_from_app;
const byte buffSize = 30;
byte inputBuffer[buffSize];
const byte startMarker = 255;
const byte endMarker = 254;
byte bytesRecvd = 0;
boolean data_received = false;

//-----Motor zamanlaması ve ateşleme ile ilgili değişkenler
bool is_firing =  false;
bool can_fire =  false;
bool recoiling = false;

unsigned long firing_start_time = 0;
unsigned long firing_current_time = 0;
const long firing_time = 150;

unsigned long recoil_start_time = 0;
unsigned long recoil_current_time = 0;
const long recoil_time = 2 * firing_time;

const byte motor_pin =  12;
boolean motors_ON = false;

//8===========================D

void setup()
{
  //-----motor pimi modunu tanımlama
  pinMode(motor_pin, OUTPUT);
  digitalWrite(motor_pin, LOW);

  //-----servoyu pinlere bağlama (Arduino Nano'da bu pinlerde pwn özelliği bulunmaktadır.)
  recoil_servo.attach(9);
  pan_servo.attach(10);
  tilt_servo.attach(11);

  //-----başlangıç sırası
  recoil_servo.write(recoil_rest);
  pan_servo.write(90);
  //tilt_servo.write(tilt_limit_2);
  delay(1000);
  //tilt_servo.write(tilt_limit_2 + abs((tilt_limit_2 - tilt_limit_1)/2));
  tilt_servo.write(105);


  Serial.begin(9600);  // seri haberleşmeyi başlatma
}

//8===========================D

void loop()
{
  getDataFromPC();
  set_motor();
  if (data_received) {
    move_servo();
    set_recoil();
    set_motor();
  }
  fire();
}

//8===========================D

void getDataFromPC() {

  //verilerin beklenen yapısı [başlangıç baytı, yatay miktarı, dikey miktarı, motor açık, ateşleme düğmesine basıldı, son bayt]
  //başlangıç baytı = 255
  //yatay miktarı = 0 ve 253 bayt aralığında
  //dikey miktarı = 0 ve 253 bayt aralığında
  //motor açık = 0 kapalı - 1 açık
  //ateşleme düğmesine basıldı = herhangi basım olmaması durumunda 0 - tersi için 1
  //end byte = 254

  if (Serial.available()) {  // Seri halinde veri mevcutsa

    byte_from_app = Serial.read();   //bir sonraki karakteri oku

    if (byte_from_app == 255) {     // bulunursa başlangıç baytını ara
      bytesRecvd = 0;                   //alınan baytı 0'a sıfırla
      data_received = false;
    }

    else if (byte_from_app == 254) {    // eğer bulunursa, bitiş baytını arayın
      data_received = true;                // verilerin kullanılabilmesi için data_received öğesini true olarak ayarlama
    }

    else {                            // arabelleğe alınan baytı ekle
      inputBuffer[bytesRecvd] = byte_from_app;     //giriş arabelleğine karakter ekle
      bytesRecvd++;                                // alınan artımlı bayt (bu işlem bir indeks olarak hareket eder)
      if (bytesRecvd == buffSize) {    // inputBuffer'ın doldurulması durumunda alınan bir güvenlik (bu olmamalıdır)
        bytesRecvd = buffSize - 1;    // eğer bytesReceived > buffer size'dan büyükse, bytesReceived'ı buffer size'dan daha küçük ayarla
      }
    }
  }
}

//8===========================D

void move_servo() {
  
  byte pan_servo_position = map(inputBuffer[0], 0, 253, pan_limit_2, pan_limit_1);//inputbuffer değerini yatay servo pozisyon değerine dönüştür
  pan_servo.write(pan_servo_position); //yatay servo konumunu ayarla
  byte tilt_servo_position = map(inputBuffer[1], 0 , 253, tilt_limit_2, tilt_limit_1); //inputbuffer değerini dikey servo pozisyon değerine dönüştür
  tilt_servo.write(tilt_servo_position); //dikey servo konumunu ayarla
}

//8===========================D

void set_recoil() {

  if (inputBuffer[3] == 1) {        //eğer ateşlemeye basılırsa
    if (!is_firing && !recoiling) { //ve zaten ateş etmiyor veya geri tepmiyorsa
      can_fire = true;              
    }
  }
  else {                  // eğer ateşlemeye basılmazsa
    can_fire = false;     
  }
}

//8===========================D

void set_motor() {
  //-----ırfp250n mosfet kullanarak motorları çalıştırma ve durdurma

  if (inputBuffer[2] == 1) {                //ekrana dokunulursa
    digitalWrite(motor_pin, HIGH);          //motoru aç
    motors_ON = true;
  }
  else {                                   //ekrana dokunulmazsa
    digitalWrite(motor_pin, LOW);          //motoru kapat
    motors_ON = false;

  }
}

//8===========================D

void fire() { //motor baytı açıksa, motoru aç ve açık kaldığını kontrol et

  if (can_fire && !is_firing && motors_ON) {
    //if (can_fire && !is_firing) {
    firing_start_time = millis();
    recoil_start_time = millis();
    is_firing = true;
  }

  firing_current_time = millis();
  recoil_current_time = millis();

  if (is_firing && firing_current_time - firing_start_time < firing_time) {
    recoil_servo.write(recoil_pushed);
  }
  else if (is_firing && recoil_current_time - recoil_start_time < recoil_time) {
    recoil_servo.write(recoil_rest);
  }
  else if (is_firing && recoil_current_time - recoil_start_time > recoil_time) {
    is_firing = false;
  }

}
